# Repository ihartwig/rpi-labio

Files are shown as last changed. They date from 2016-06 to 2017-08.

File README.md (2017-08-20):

# rpi-labio

Together with the JTAG debugger and cover with motor mounts, this Raspberry Pi breakout board forms a complete kit for embedded systems labs in ARM baremetal and linux. This kit has been used for several semesters at [CMU ECE](https://www.ece.cmu.edu/~ece349/).

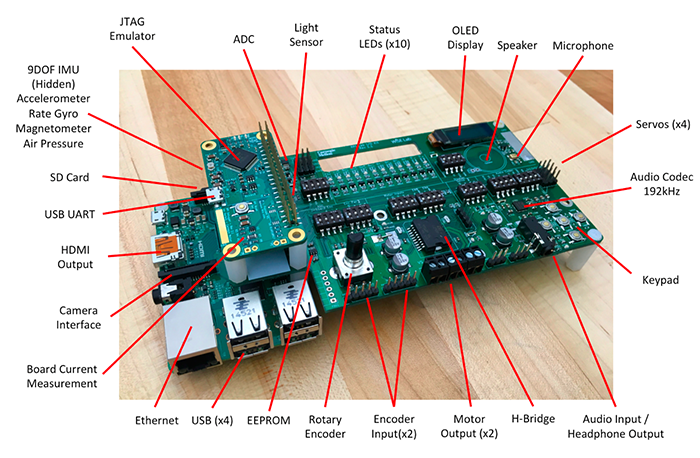
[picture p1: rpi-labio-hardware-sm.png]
labio hardware list


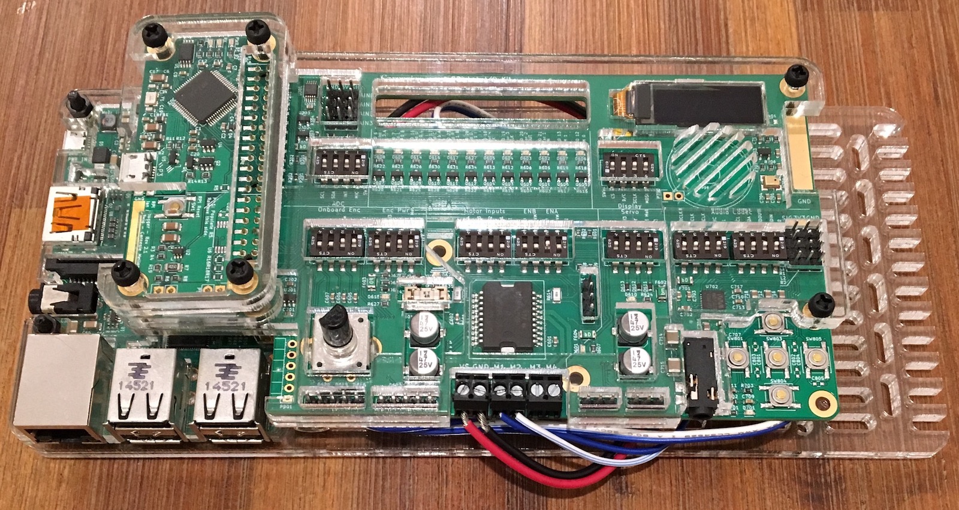
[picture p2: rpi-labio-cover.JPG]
labio with protective cover


This single, compact board extends a Raspberry Pi 0 or 2 for a full range of labs combining embedded processing with real-world sensors and transducers. All parts are optional and can be disconnected in favor of other plugged in hardware. Together, the sensor kit exercises almost all serial and digital I/O available on the Raspberry Pi. For more details check out the [schematic](https://github.com/ihartwig/rpi-labio/blob/master/pcb/labio.pdf) and [board](https://github.com/ihartwig/rpi-labio/blob/master/pcb/svg/labio-brd.svg).

## I/O

* OLED Display
* 10-DOF IMU (Accelerometer + Compass + Gyroscope + Pressure)
* Audio Codec with speaker, microphone, and headset port
* D-Pad Buttons
* Servo Headers with configurable voltage
* Full-Bridge for 2 DC motors or 1 stepper motor
* Encoder Headers with configurable voltage
* Rotary Encoder
* ADC with optional differential amplifier
* LED indicators on most digital outputs

## Example Labs

* Arcade style games with screen, d-pad, and rotary encoder
* Guitar tuner with microphone, speaker, codec, and screen
* MP3 player with codec and headphone port
* The useless machine with servo and buttons
* Self-balancing robot with IMU, motor controller, and encoders
* Energy-aware computing with ADC and power shunt (on board for motors, off board for RPi)
* And more!

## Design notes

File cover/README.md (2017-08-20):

# rpi-labio Protective Cover

The rpi-labio, debugger, and pi kit can come with a laser cut acrylic and standoff kit for increased robustness. The cover consists of 2 layers of 3mm (1/8") acrylic on the top and bottom of the boards. The layers can be configured for Pi 0/2/3 and several Pololu motor mounts including a dual-motor self-balancing kit.

The mounting holes on Raspberry Pi boards are 2.75mm (for M2.5 screws), but the labio and debugger have 3mm holes (for M3 or 4-40 screws). Nylon M3 or 4-40 screws are a tight fit but easier to find. Nylon screws are also recommended to keep the outside of the cover plastic.

Cover variants B, C, D require 1 sq. ft. of acrylic sheet. Variant A requires 1.33 sq. ft. of acrylic sheet (4 sq. ft. for 3).

## Top Layers

The layers on top of the debugger and labio boards are common to all configurations.

With 8.5mm tall stacking headers (11mm board to board) use 2x layer 9 per cover. If you have taller headers (14mm board to board), use 3x layer 9 per cover.

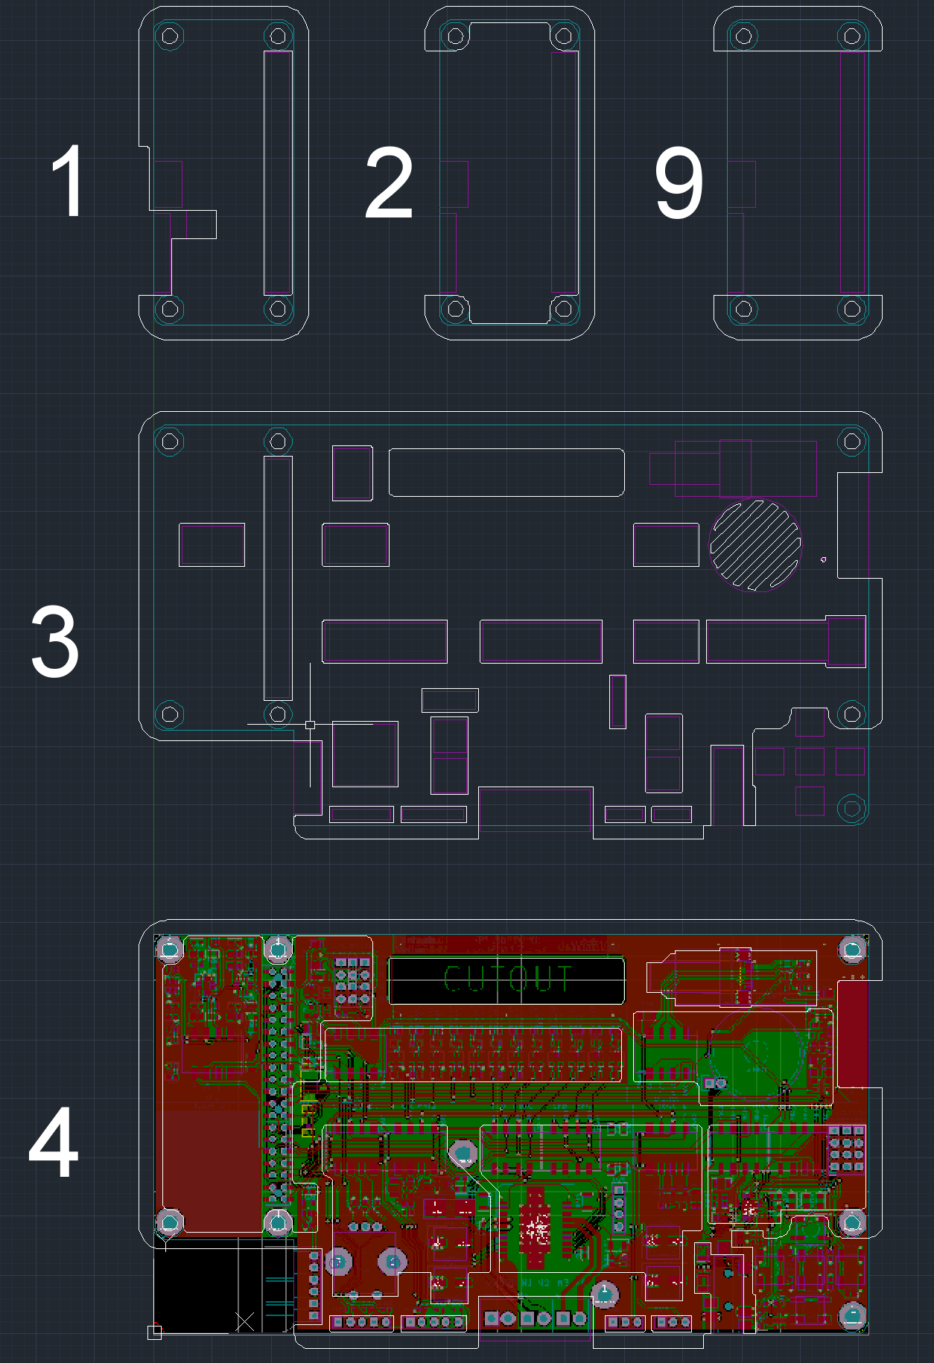
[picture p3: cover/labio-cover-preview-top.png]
labio cover preview top


## Base Layers for Pi 2/3

The base layer for Pi 2 extends beyond the labio board on both sides and includes extra protectors for the top of the Pi 2. The extra space can be used to mount a Pololu encoder gear motor or other electromechanical accessories. The smaller base is sized for 1x 20D, 2x 20D, or 1x 25D motor, and the larger base fits 1x 37D motor.

Variant A: Pi 2/3 with 37D motor
Variant B: Pi 2/3 with 1x 20D, 2x 20D, or 1x 25D motor

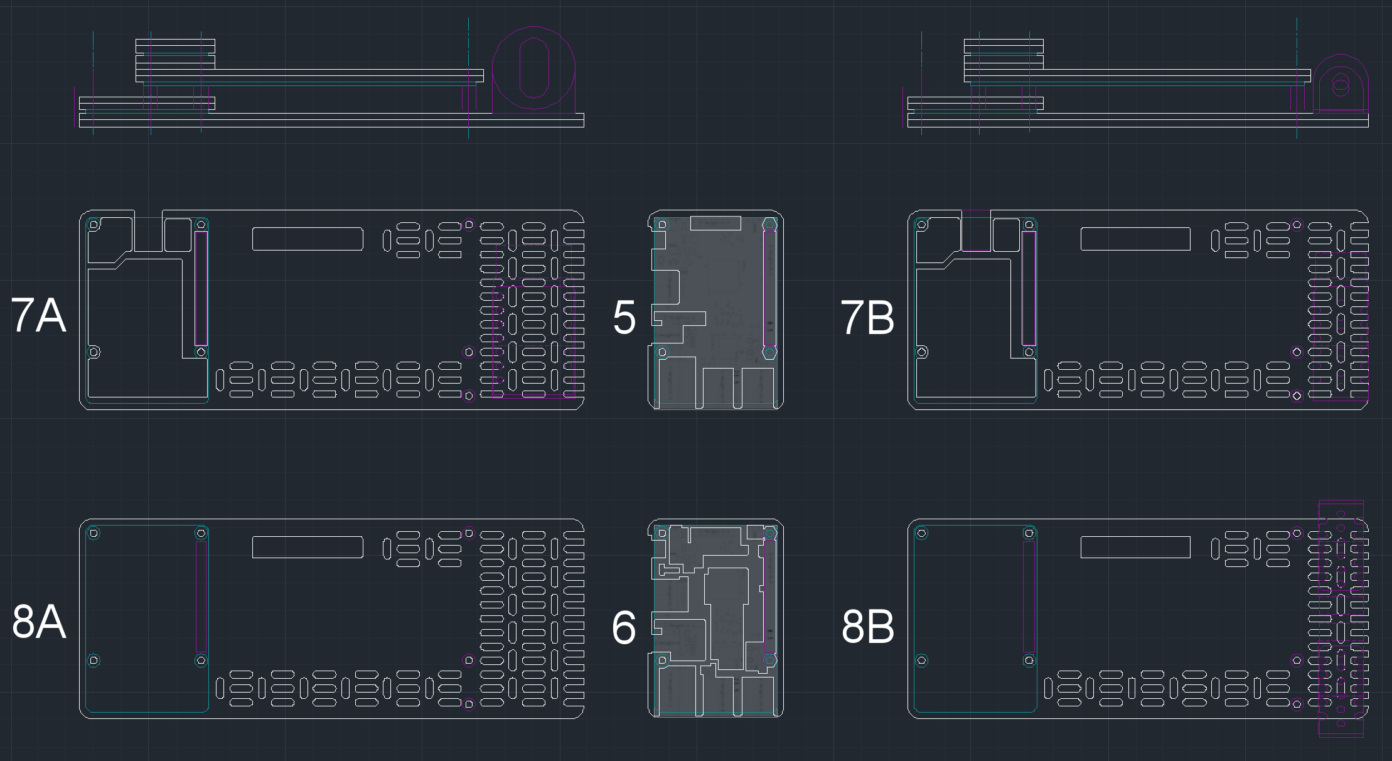
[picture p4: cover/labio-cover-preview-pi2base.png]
labio cover preview pi2 base


Orderable Parts

Description | Qty | Vendor | Vendor PN
------------|-----|--------|----------
debugger, labio 2x20 stacking header | 2 | Pololu or Toby (Samtec) | [2748](https://www.pololu.com/product/2748) or [REF-182684-02](https://www.toby.co.uk/content/catalogue/products.aspx?series=REF-18xxxx-0x)
M3 11mm or 4-40 7/16" female-female standoffs | 4 | Amico | [a12092200ux0064](http://a.co/bL8HFg3)
M3 12mm or 4-40 1/2" nylon screws | 6 | Electronics-Salon | [SCW-NLB/M3x12-100](http://a.co/i08gfTl)
M3 25mm or 4-40 1" nylon screws | 6 | uxcell | [a15062200ux0426](a15062200ux0426)
M3 or 4-40 hex nuts | 4 | uxcell | [a16033100ux0563](http://a.co/68ee8uG)
M3 or 4-40 flat washers | 6 | uxcell | [a15090700ux0161](http://a.co/8erwuEw)

We have some kits built with taller headers resulting in 14mm board to board (rather than 11mm). Adjust the orderable parts as below. Not recommended for new builds.

Description | Qty | Vendor | Vendor PN
------------|-----|--------|----------
debugger, labio 2x20 stacking header | 2 | Adafruit | [1979](https://www.adafruit.com/product/1979)
M3 14mm female-female standoffs | 4 | uxcell | [a15081800ux0063](http://a.co/6xW5v0G)
M3 12mm or 4-40 1/2" nylon screws | 6 | Electronics-Salon | [SCW-NLB/M3x12-100](http://a.co/i08gfTl)
M3 30mm or 4-40 1 1/4" nylon screws | 6 | uxcell | [SYNCTEA049689](http://a.co/3Iv3Hqf)
M3 or 4-40 hex nuts | 4 | uxcell | [a16033100ux0563](http://a.co/68ee8uG)
M3 or 4-40 flat washers | 6 | uxcell | [a15090700ux0161](http://a.co/8erwuEw)

## Base Layers for Pi 0/0W

The base layer for Pi 0 can optionally extend to the right to support Pololu 1x 20D, 2x 20D, or 1x 25D motor.

Variant C: Pi 0/0W with 1x 20D, 2x 20D, or 1x 25D motor
Variant D: Pi 0/0W only

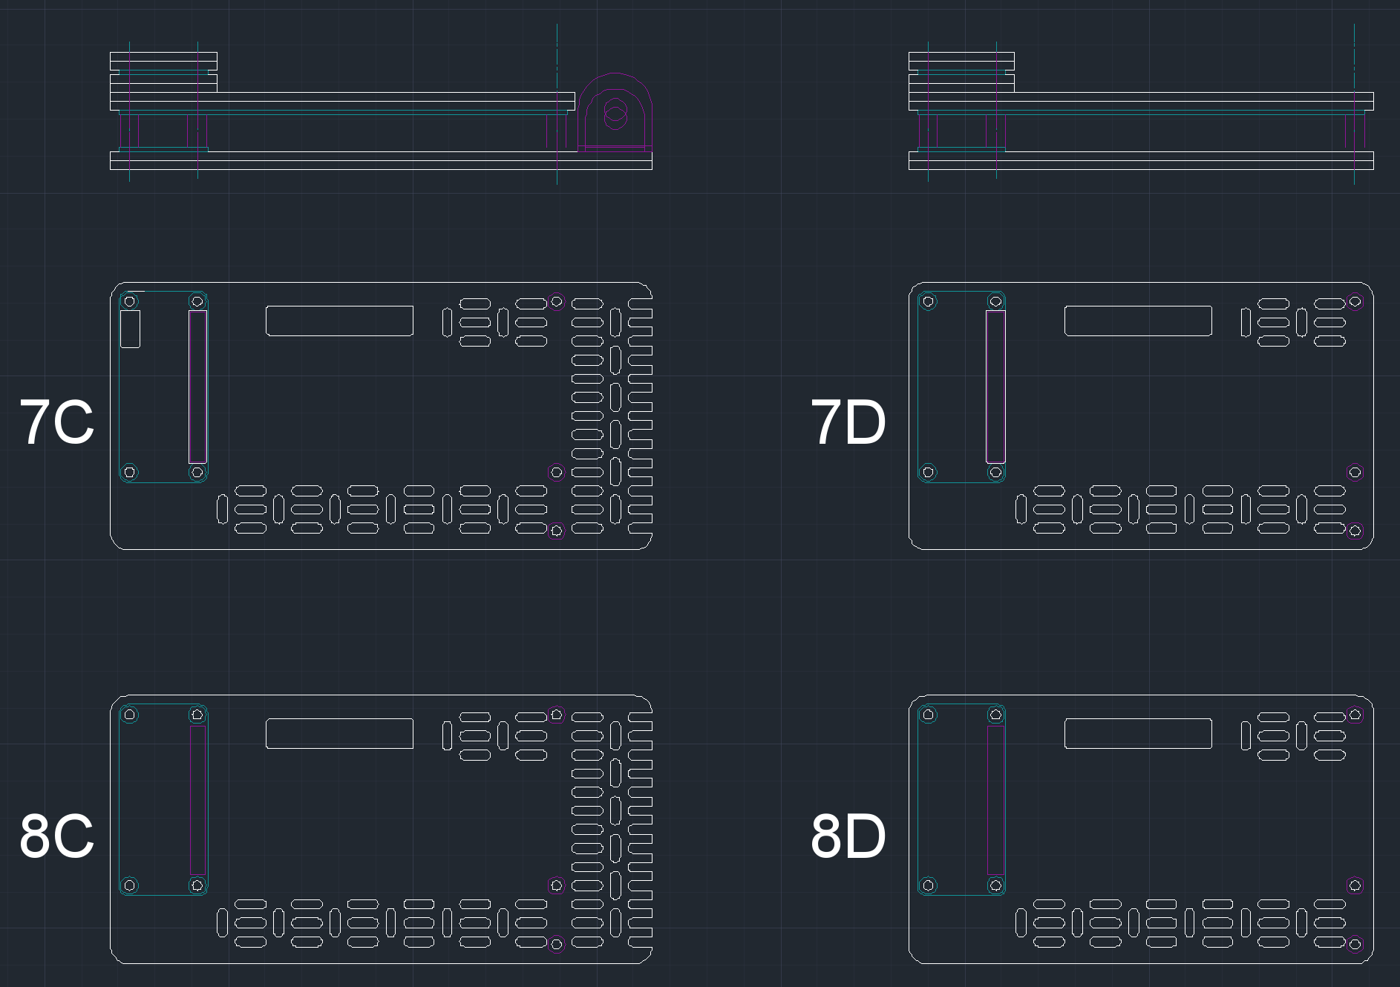
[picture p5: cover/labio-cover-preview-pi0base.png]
labio cover preview pi0 base


Orderable Parts

Description | Qty | Vendor | Vendor PN
------------|-----|--------|----------
debugger, labio 2x20 stacking header | 2 | Pololu or Toby (Samtec) | [2748](https://www.pololu.com/product/2748) or [REF-182684-02](https://www.toby.co.uk/content/catalogue/products.aspx?series=REF-18xxxx-0x)
M3 11mm or 4-40 7/16" female-female standoffs | 6 | Amico | [a12092200ux0064](http://a.co/bL8HFg3)
M3 12mm or 4-40 1/2" nylon screws | 8 | Electronics-Salon | [SCW-NLB/M3x12-100](http://a.co/i08gfTl)
M3 25mm or 4-40 1" nylon screws | 4 | uxcell | [a15062200ux0426](a15062200ux0426)
M3 or 4-40 flat washers | 6 | uxcell | [a15090700ux0161](http://a.co/8erwuEw)

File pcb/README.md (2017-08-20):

# rpi-labio/pcb

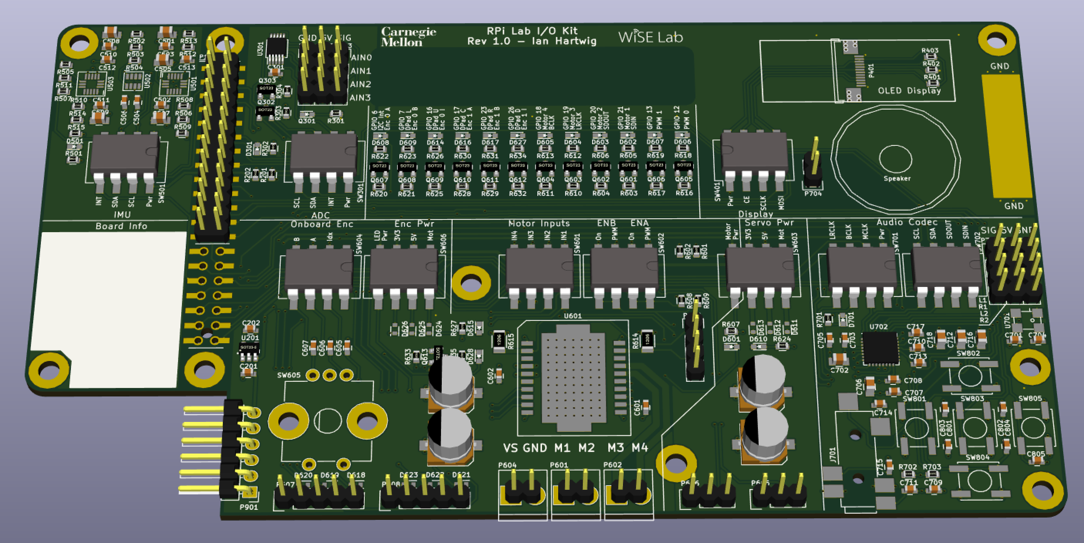
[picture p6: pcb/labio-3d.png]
labio 3d


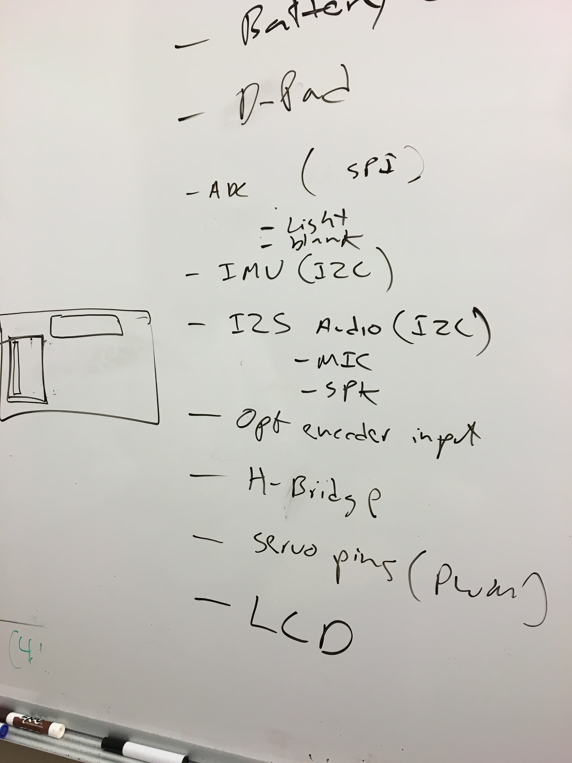
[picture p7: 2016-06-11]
docs/modules.jpg

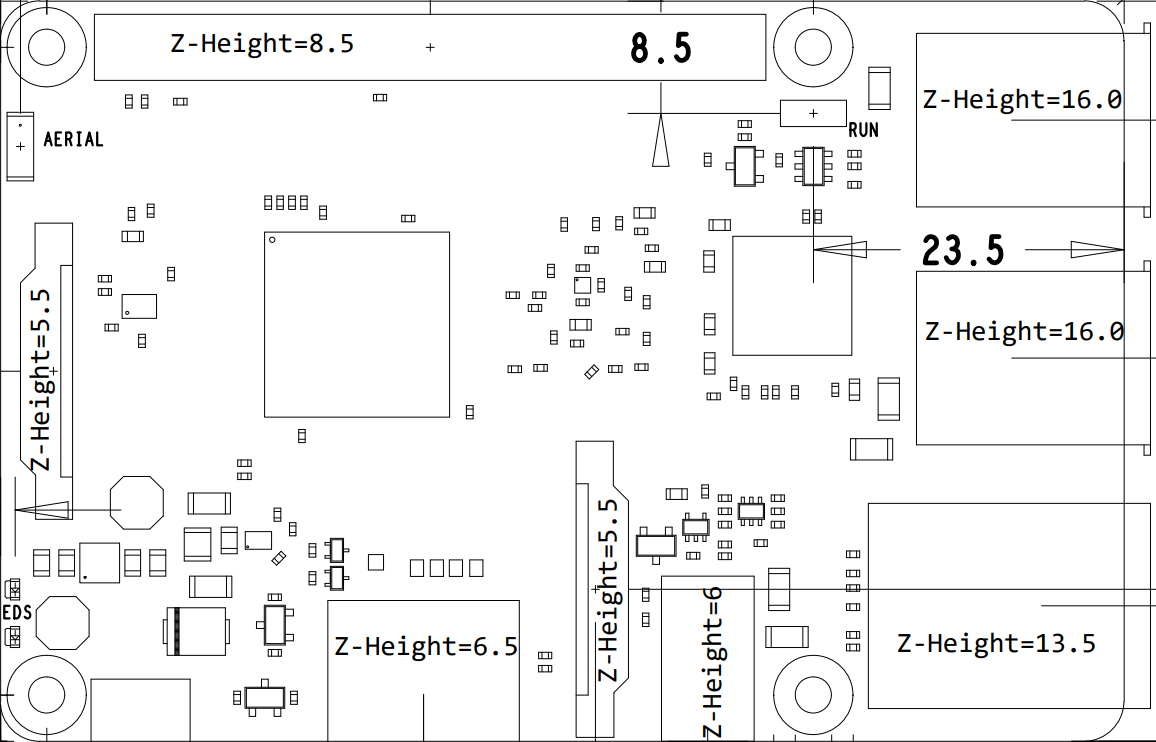
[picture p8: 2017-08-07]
cover/ref-pi3-board.png

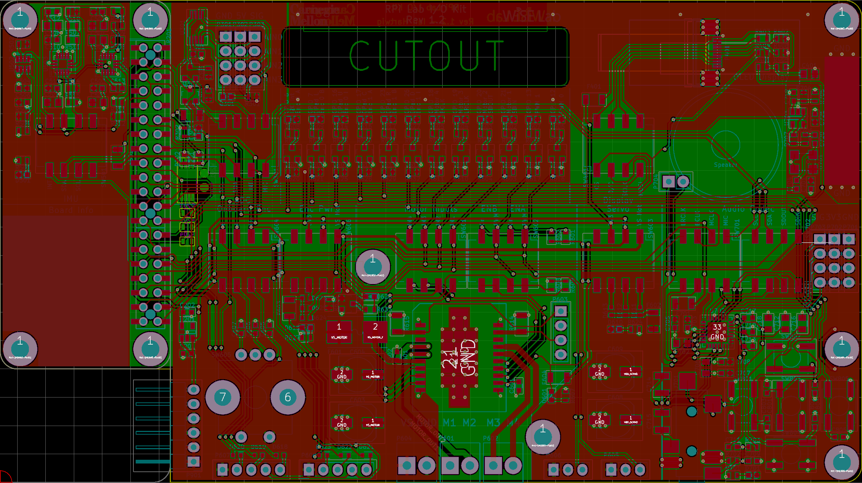
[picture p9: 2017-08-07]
cover/ref-labio-board.png

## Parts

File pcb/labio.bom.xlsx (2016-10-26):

Source | /Users/ihartwig/repos/rpi-labio/pcb/labio.sch
Kicad Rev | Eeschema 4.0.0-stable
Generated Date | Monday July 25 2016 'PMt' 11:51:32 PM
Title | Raspberry Pi Embedded Lab I/O
Company | Carnegie Mellon University
Revision | 1.2
Date Issue | 2016-08-24
Reference | Value | Footprint | Qty | Type | Mfg | Mfg Part No | Description | Digikey Part No | Comments
C201, C202, C301, C502, C503, C504, C506, C510, C511, C601, C602, C605, C606, C607, C701, C703, C705, C707, C708, C710, C713, C717, C721 | 0.1uF | Capacitors_SMD:C_0603 | 23 | SMT | Murata | GRM188R71C104KA01D | CAP CER 0.1uF ±10% 16V X7R 0603
C401 | dnp-4.7uF | Capacitors_SMD:C_0805 | 1 | DNS | Samsung | CL21A475KPFNNNG | 4.7µF 10V Ceramic Capacitor X5R 0805 | 1276-6464-1-ND | http://www.digikey.com/product-detail/en/samsung-electro-mechanics-america-inc/CL21A475KPFNNNG/1276-6464-1-ND/5958092
C501, C505, C507, C508, C509, C702, C706, C712, C716, C718 | 4.7uF | Capacitors_SMD:C_0805 | 10 | SMT | Samsung | CL21A475KPFNNNG | 4.7µF 10V Ceramic Capacitor X5R 0805 | 1276-6464-1-ND | http://www.digikey.com/product-detail/en/samsung-electro-mechanics-america-inc/CL21A475KPFNNNG/1276-6464-1-ND/5958092
C512 | 0.01uF-25V | Capacitors_SMD:C_0603 | 1 | SMT | Murata | GRM188R71H103KA01D | CAP CER 0.01uF ±10% 50V X7R 0603
C513 | 0.22uF | Capacitors_SMD:C_0603 | 1 | SMT | Murata | GRM188R71C224KA01D | CAP CER 0.22UF ±10% 16V X7R 0603
C603, C604, C608, C609 | 47uF | Capacitors_SMD:c_elec_6.3x5.8 | 4 | SMT | Nichicon | UWR1E470MCL1GB | 47µF 25V Aluminum Capacitors Radial, Can - SMD 2000 Hrs @ 85°C | 493-14562-1-ND | http://www.digikey.com/product-detail/en/nichicon/UWR1E470MCL1GB/493-14562-1-ND/5800262
C709 | 220pF | Capacitors_SMD:C_0603 | 1 | SMT | Murata | GRM188R71H221KA01D | CAP CER 220PF ±10% 50V X7R 0603
C704, C711, C719, C720 | 1uF | Capacitors_SMD:C_0603 | 4 | SMT | Samsung | CL10B105KP8NNNC | 1µF 10V Ceramic Capacitor X7R 0603 (1608 Metric) 0.063" L x 0.031" W (1.60mm x 0.80mm) | 1276-1946-1-ND | http://www.digikey.com/product-detail/en/samsung-electro-mechanics-america-inc/CL10B105KP8NNNC/1276-1946-1-ND/3890032
C714, C715 | 220uF | Capacitors_SMD:C_1210 | 2 | SMT | Samsung | CL32A227MQVNNNE | 220µF 6.3V Ceramic Capacitor X5R 1210 | 1276-3375-1-ND | http://www.digikey.com/product-detail/en/samsung-electro-mechanics-america-inc/CL32A227MQVNNNE/1276-3375-1-ND/3891461
C801, C802, C803, C804, C805 | dnp | Capacitors_SMD:C_0603 | 5 | DNS
D301, D501, D601, D602, D603, D604, D605, D606, D607, D608, D609, D610, D614, D615, D616, D617, D627, D628, D701 | Led_Small | LEDs:LED-0603 | 19 | SMT | Lite-On | LTST-C190GKT | LED GREEN CLEAR 0603 SMD | 160-1183-1-ND | http://www.digikey.com/product-detail/en/lite-on-inc/LTST-C190GKT/160-1183-1-ND/269255
D611, D612, D613, D618, D619, D620, D621, D622, D623, D624, D625, D626 | D_Small | Diodes_SMD:SOD-523 | 12 | SMT | Panasonic | DB2S20500L | DIODE SCHOTTKY 15V 200MA SSMINI2 | DB2S20500LCT-ND | http://www.digikey.com/product-detail/en/panasonic-electronic-components/DB2S20500L/DB2S20500LCT-ND/2326091
F301, F401, F501, F603, F604, F701 | F_Small | Resistors_SMD:R_1206 | 6 | SMT | Bel Fuse | 0ZCJ0010FF2E | PTC RESTTBLE 0.10A 60V CHIP 1206 | 507-1794-1-ND | http://www.digikey.com/product-detail/en/bel-fuse-inc/0ZCJ0010FF2E/507-1794-1-ND/4156222
F601 | F_Small | labio-special:OMNI-BLOCK_Fuse_10x5mm_Littelfuse | 1 | SMT | Littelfuse | 0154004.DRT | FUSE BRD MNT 4A 125VAC/VDC 2SMD | F1309CT-ND | http://www.digikey.com/product-detail/en/littelfuse-inc/0154004.DRT/F1309CT-ND/266657
F602 | F_Small | Resistors_SMD:R_1206 | 1 | SMT | Bel Fuse | 0ZCJ0050AF2E | PTC RESTTBLE 0.50A 24V CHIP 1206 | 507-1803-1-ND | http://www.digikey.com/product-detail/en/bel-fuse-inc/0ZCJ0050AF2E/507-1803-1-ND/4156312
G1 | CMU_LOGO | labio-special:cmu_logo_fsilk_3.7mm | 1 | DNS
G2 | WISE_LOGO | labio-special:wise_logo_fsilk_2.5mm | 1 | DNS
G3 | CMU_LOGO | labio-special:cmu_logo_fcu_3.7mm | 1 | DNS
G4 | WISE_LOGO | labio-special:wise_logo_fcu_2.5mm | 1 | DNS
H1001, H1002, H1003, H1004, H1005, H1006, H1007, H1008, H1009 | hole | labio-special:hole-m3 | 9 | DNS
IC201 | AT24CS32-XHM | Housings_SSOP:TSSOP-8_4.4x3mm_Pitch0.65mm | 1 | DNS
J701 | JACK_TRRS_6PINS | labio-special:3.5mm-Jack-CUI-SJ-4351X | 1 | SMT | CUI Inc | SJ-43515RS-SMT-TR | 3.50mm (0.141", 1/8", Mini Plug) - Headphone Phone Jack Multiple Connector Solder | CP-43515RSSJCT-ND | http://www.digikey.com/product-detail/en/cui-inc/SJ-43515RS-SMT-TR/CP-43515RSSJCT-ND/669732
P201 | CONN_02X20 | labio-special:Pin_Header_Straight_TH-SMT-NoPaste_2x20 | 1 | DNS
P301, P302, P303, P603, P701, P702, P703 | CONN_01X04 | Pin_Headers:Pin_Header_Straight_1x04 | 7 | TH | Harwin, Inc. | M20-9990446 | 4 Positions Header, Unshrouded, Breakaway Connector 0.100" (2.54mm) Through Hole Tin | 952-2266-ND | http://www.digikey.com/product-detail/en/harwin-inc/M20-9990446/952-2266-ND/3728230
P401 | SFV12R-1ST__HLF | labio-special:SFVxxR-xSTxxHLF | 1 | SMT | Amphenol FCI | SFV12R-3STBE1HLF | 12 Position FPC Connector Contacts, Bottom 0.020" (0.50mm) Surface Mount, Right Angle | 609-5196-1-ND | Could also use SFV12R-1STE1HLF. http://www.digikey.com/product-detail/en/amphenol-fci/SFV12R-3STBE1HLF/609-5196-1-ND/5967741
P601, P602, P604 | CONN_01X02 | labio-special:Pin_Header_Straight_1x02_Pitch3.5mm | 3 | TH | On Shore Technology, Inc. | OSTTE020104 | 2 Position Wire to Board Terminal Block Horizontal with Board 0.138" (3.50mm) Through Hole | ED2740-ND | http://www.digikey.com/product-detail/en/on-shore-technology-inc/OSTTE020104/ED2740-ND/2351816
P605, P606 | CONN_01X03 | Pin_Headers:Pin_Header_Straight_1x03 | 2 | TH | Harwin, Inc. | M20-9990346 | 3 Positions Header, Unshrouded, Breakaway Connector 0.100" (2.54mm) Through Hole Tin | 952-2264-ND | http://www.digikey.com/product-detail/en/harwin-inc/M20-9990346/952-2264-ND/3728228
P607, P608 | CONN_01X05 | Pin_Headers:Pin_Header_Straight_1x05 | 2 | TH | Harwin, Inc. | M20-9990546 | 5 Positions Header, Unshrouded, Breakaway Connector 0.100" (2.54mm) Through Hole Tin | 952-2268-ND | http://www.digikey.com/product-detail/en/harwin-inc/M20-9990546/952-2268-ND/3728232
P704 | CONN_01X02 | Pin_Headers:Pin_Header_Straight_1x02 | 1 | DNS
P901 | CONN_01X06 | Pin_Headers:Pin_Header_Angled_1x06 | 1 | DNS
Q301 | PHOTOTRANSISTOR | LEDs:LED-0603 | 1 | SMT | Everlight Electronics | PT19-21B/L41/TR8 | PHOTOTRANSISTOR FLAT BK MINI SMD | 1080-1383-1-ND | http://www.digikey.com/product-detail/en/everlight-electronics-co-ltd/PT19-21B-L41-TR8/1080-1383-1-ND/2676117
Q302, Q303, Q601, Q602, Q603, Q604, Q605, Q606, Q607, Q608, Q609, Q610, Q611, Q612, Q613 | Q_NMOS_GSD | TO_SOT_Packages_SMD:SOT-23 | 15 | SMT | ON Semiconductor | NTR5103NT1G | MOSFET N-CH 60V 0.26A SOT23 | NTR5103NT1GOSCT-ND | http://www.digikey.com/product-detail/en/on-semiconductor/NTR5103NT1G/NTR5103NT1GOSCT-ND/5801875
R201, R202, R301, R703 | 2.2k | Resistors_SMD:R_0603 | 4 | SMT | Vishay Dale | CRCW06032K20FKEA | RES SMD 2.2K OHM 1% 1/10W 0603
R203 | dnp-10k | Resistors_SMD:R_0603 | 1 | DNS
R204, R205 | dnp-3.9k | Resistors_SMD:R_0603 | 2 | DNS
R302, R501, R605, R606, R607, R612, R613, R618, R619, R622, R623, R624, R626, R627, R630, R631, R634, R635, R701 | 220 | Resistors_SMD:R_0603 | 19 | SMT | Vishay Dale | CRCW0603220RFKEA | RES SMD 220 OHM 1% 1/10W 0603
R303, R304, R601, R602, R704, R705, R706 | 10k | Resistors_SMD:R_0603 | 7 | SMT | Vishay Dale | CRCW060310K0FKEA | RES SMD 10K OHM 1% 1/10W 0603
R401, R402, R403, R502, R504, R506, R507, R508, R509, R510, R511, R513, R515 | 0 | Resistors_SMD:R_0603 | 13 | SMT | Vishay Dale | CRCW06030000Z0EA | RES SMD 0.0OHM JUMPER 1/10W 0603
R404, R406, R503, R512, R514 | dnp-0 | Resistors_SMD:R_0603 | 5 | DNS | Vishay Dale | CRCW06030000Z0EA | RES SMD 0.0OHM JUMPER 1/10W 0603
R405 | dnp-47k | Resistors_SMD:R_0603 | 1 | DNS | Vishay Dale | CRCW060347K0FKEA | RES SMD 47K OHM 1% 1/10W 0603
R603, R604, R608, R609, R610, R611, R616, R617, R620, R621, R625, R628, R629, R632, R633 | 20k | Resistors_SMD:R_0603 | 15 | SMT | Vishay Dale | CRCW060320K0FKEA | RES SMD 20K OHM 1% 1/10W 0603
R614, R615 | 0.01 | Resistors_SMD:R_1206 | 2 | SMT | Samsung | RUW3216FR100CS | RES SMD 0.1 OHM 1% 1W 1206 | 1276-6187-1-ND | http://www.digikey.com/product-detail/en/samsung-electro-mechanics-america-inc/RUW3216FR100CS/1276-6187-1-ND/3969159
R702 | 47k | Resistors_SMD:R_0603 | 1 | SMT | Vishay Dale | CRCW060347K0FKEA | RES SMD 47K OHM 1% 1/10W 0603
R707 | 820k | Resistors_SMD:R_0603 | 1 | SMT | Vishay Dale | CRCW0603820KFKEA | RES SMD 820K OHM 1% 1/10W 0603
SW301, SW401, SW501, SW601, SW602, SW603, SW604, SW606, SW701, SW702 | DIP_SWITCH_X04 | labio-special:DIP-8_W7.62mm_SMT | 10 | SMT | CTS Electrocomponents | 219-4MST | Dip Switch SPST 4 Position Surface Mount Slide (Standard) Actuator 100mA 20VDC | CT2194MST-ND | http://www.digikey.com/product-detail/en/cts-electrocomponents/219-4MST/CT2194MST-ND/223197
SW605 | ROT_ENC | labio-special:Rot-Enc-12mm-Horiz-Button | 1 | TH | Bourns | PEC12R-4220F-N0024 | 12 mm Incremental Encoder | PEC12R-4220F-N0024-ND | http://www.digikey.com/product-detail/en/bourns-inc/PEC12R-4220F-N0024/PEC12R-4220F-N0024-ND/4499652
SW801, SW802, SW803, SW804, SW805 | SW_PUSH | Buttons_Switches_SMD:SW_SPST_EVPBF | 5 | SMT | TE Connectivity | FSMCTTR | SWITCH TACTILE SPST-NO 0.02A 15V | 450-2133-1-ND | http://www.digikey.com/product-detail/en/FSMCTTR/450-2133-1-ND/5343813
U201 | AP7365_SOT-23-5 | TO_SOT_Packages_SMD:SOT-23-5 | 1 | SMT | Diodes | AP7365-33WG-7 | Linear Voltage Regulator IC Positive Fixed 1 Output 3.3V 600mA SOT-25 | AP7365-33WG-7DICT-ND | http://www.digikey.com/product-detail/en/diodes-incorporated/AP7365-33WG-7/AP7365-33WG-7DICT-ND/5267107
U301 | ADS1015 | Housings_SSOP:MSOP-10_3x3mm_Pitch0.5mm | 1 | SMT | TI | ADS1015IDGSR | IC ADC 12BIT I2C 3.3KSPS 10MSOP | 296-41185-1-ND | http://www.digikey.com/product-detail/en/texas-instruments/ADS1015IDGSR/296-41185-1-ND/5222640
U401 | CFAL12832D-B |  | 1 | DNS | Crystalfontz | CFAL12832D-B | 128x32 I2C Graphic OLED - ZIF | Not Available | https://www.crystalfontz.com/product/cfal12832db-graphic-128x32-oled
U501 | LSM303D | labio-special:LGA-16_3x3mm_Pitch0.5mm_ST | 1 | SMT | ST Microelectronics | LSM303DTR | ACCELEROMETER 3D MAGNO 16LGA | 497-13819-1-ND | http://www.digikey.com/product-detail/en/stmicroelectronics/LSM303DTR/497-13819-1-ND/4245539
U502 | BMP280 | labio-special:LGA-8_2.5x2.0mm_Pitch0.65mm_BMx280 | 1 | SMT | Bosch | BMP280 | Board Mount Pressure Sensors Digital Barometer 2.7uA, 300-1200hPa | Not Available | http://www.mouser.com/ProductDetail/Bosch-Sensortec/BMP280/
U503 | L3GD20H | labio-special:LGA-16_3x3mm_Pitch0.5mm_ST | 1 | SMT | ST Microelectronics | L3GD20HTR | IC MEMS MOTION SENSOR 16LLGA | 497-13931-1-ND | http://www.digikey.com/product-detail/en/stmicroelectronics/L3GD20HTR/497-13931-1-ND/4357644
U601 | L298P_PowerSO20 | labio-special:PowerSO20 | 1 | SMT | ST Microelectronics | L298P013TR | IC BRIDGE DRIVER PAR 20POWERSO | 497-3624-1-ND | http://www.digikey.com/product-detail/en/stmicroelectronics/L298P013TR/497-3624-1-ND/677613
U701 | SPU0410HR5H | labio-special:SPU0410HR5H | 1 | SMT | Knowles | SPU0410HR5H-PB | 100Hz ~ 10kHz Analog Microphone MEMS (Silicon) Omnidirectional (-42dB ±3dB @ 94dB SPL) Surface Mount | 423-1138-1-ND | http://www.digikey.com/product-detail/en/knowles/SPU0410HR5H-PB/423-1138-1-ND/2420982
U702 | WM8750 | Housings_DFN_QFN:QFN-32-1EP_5x5mm_Pitch0.5mm | 1 | SMT | Cirrus Logic | WM8750CJLGEFL | IC CODEC STEREO PORTABLE 32QFN | 598-2392-ND | http://www.digikey.com/product-detail/en/cirrus-logic-inc/WM8750CJLGEFL/598-2392-ND/5409917
U703 | OPA344_SOT23-5 | TO_SOT_Packages_SMD:SOT-23-5 | 1 | SMT | TI | OPA344NA/250 | IC OPAMP GP 1MHZ RRO SOT23-5 | OPA344NACT-ND | http://www.digikey.com/product-detail/en/texas-instruments/OPA344NA-250/OPA344NACT-ND/362263
W201, W202 | TEST_1P | Measurement_Points:Measurement_Point_Round-SMD-Pad_Small | 2 | DNS

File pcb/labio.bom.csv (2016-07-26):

Source | /Users/ihartwig/repos/rpi-labio/pcb/labio.sch
Kicad Rev | Eeschema 4.0.0-stable
Generated Date | Tuesday | July 26 | 2016 'AMt' 01:45:02 AM
Title | Not Set
Company | Not Set
Revision | Not Set
Date Issue | Not Set
Reference | Value | Footprint | Library | Library Ref
P1 | CONN_02X20 | labio-special:Pin_Header_Straight_TH-SMT-NoPaste_2x20 | conn | CONN_02X20
IC201 | dnp-AT24CS32-XHM | Housings_SSOP:TSSOP-8_4.4x3mm_Pitch0.65mm | memory | AT24CS32-XHM
R203 | dnp-10k | Resistors_SMD:R_0603 | device | R_Small
R204 | dnp-3.9k | Resistors_SMD:R_0603 | device | R_Small
R205 | dnp-3.9k | Resistors_SMD:R_0603 | device | R_Small
W202 | TEST_1P | Measurement_Points:Measurement_Point_Round-SMD-Pad_Small | conn | TEST_1P
W201 | TEST_1P | Measurement_Points:Measurement_Point_Round-SMD-Pad_Small | conn | TEST_1P
R202 | 4.7k | Resistors_SMD:R_0603 | device | R_Small
R201 | 4.7k | Resistors_SMD:R_0603 | device | R_Small
U201 | AP7365_SOT-23-5 | TO_SOT_Packages_SMD:SOT-23-5 | labio-special | AP7365_SOT-23-5
C201 | 0.1uF | Capacitors_SMD:C_0603 | device | C_Small
C202 | 0.1uF | Capacitors_SMD:C_0603 | device | C_Small
U301 | ADS1015 | Housings_SSOP:MSOP-10_3x3mm_Pitch0.5mm | labio-special | ADS1015
P301 | CONN_01X04 | Pin_Headers:Pin_Header_Straight_1x04 | conn | CONN_01X04
P302 | CONN_01X04 | Pin_Headers:Pin_Header_Straight_1x04 | conn | CONN_01X04
P303 | CONN_01X04 | Pin_Headers:Pin_Header_Straight_1x04 | conn | CONN_01X04
C301 | 0.1uF | Capacitors_SMD:C_0603 | device | C_Small
Q301 | PHOTOTRANSISTOR | LEDs:LED-0603 | labio-special | PHOTOTRANSISTOR
R301 | 1.5k | Resistors_SMD:R_0603 | device | R_Small
SW301 | DIP_SWITCH_X04 | labio-special:DIP-8_W7.62mm_SMT | labio-special | DIP_SWITCH_X04
D301 | Led_Small | LEDs:LED-0603 | device | Led_Small
R302 | 220 | Resistors_SMD:R_0603 | device | R_Small
Q303 | Q_NMOS_GSD | TO_SOT_Packages_SMD:SOT-23 | device | Q_NMOS_GSD
Q302 | Q_NMOS_GSD | TO_SOT_Packages_SMD:SOT-23 | device | Q_NMOS_GSD
R304 | 10k | Resistors_SMD:R_0603 | device | R_Small
R303 | 10k | Resistors_SMD:R_0603 | device | R_Small
P401 | SFV12R-1ST__HLF | labio-special:SFVxxR-xSTxxHLF | conn | CONN_01X12
R401 | 0 | Resistors_SMD:R_0603 | device | R_Small
SW401 | DIP_SWITCH_X04 | labio-special:DIP-8_W7.62mm_SMT | labio-special | DIP_SWITCH_X04
R403 | 0 | Resistors_SMD:R_0603 | device | R_Small
R402 | 0 | Resistors_SMD:R_0603 | device | R_Small
C505 | 4.7uF | Capacitors_SMD:C_0805 | device | C_Small
C503 | 0.1uF | Capacitors_SMD:C_0603 | device | C_Small
C502 | 0.1uF | Capacitors_SMD:C_0603 | device | C_Small
C506 | 0.1uF | Capacitors_SMD:C_0603 | device | C_Small
C504 | 0.1uF | Capacitors_SMD:C_0603 | device | C_Small
SW501 | DIP_SWITCH_X04 | labio-special:DIP-8_W7.62mm_SMT | labio-special | DIP_SWITCH_X04
D501 | Led_Small | LEDs:LED-0603 | device | Led_Small
R501 | 220 | Resistors_SMD:R_0603 | device | R_Small
C501 | 4.7uF | Capacitors_SMD:C_0805 | device | C_Small
U501 | LSM303D | labio-special:LGA-16_3x3mm_Pitch0.5mm_ST | labio-special | LSM303D
C513 | 0.22uF | Capacitors_SMD:C_0603 | device | C_Small
U502 | BMP280 | labio-special:LGA-8_2.5x2.0mm_Pitch0.65mm_BMx280 | labio-special | BMP280
R509 | 0 | Resistors_SMD:R_0603 | device | R_Small
R513 | 0 | Resistors_SMD:R_0603 | device | R_Small
R506 | 0 | Resistors_SMD:R_0603 | device | R_Small
R508 | 0 | Resistors_SMD:R_0603 | device | R_Small
R512 | dnp-0 | Resistors_SMD:R_0603 | device | R_Small
C512 | 0.01uF-25V | Capacitors_SMD:C_0603 | device | C_Small
C511 | 0.1uF | Capacitors_SMD:C_0603 | device | C_Small
C510 | 0.1uF | Capacitors_SMD:C_0603 | device | C_Small
C509 | 4.7uF | Capacitors_SMD:C_0805 | device | C_Small
R511 | 0 | Resistors_SMD:R_0603 | device | R_Small
R515 | 0 | Resistors_SMD:R_0603 | device | R_Small
R507 | 0 | Resistors_SMD:R_0603 | device | R_Small
R510 | 0 | Resistors_SMD:R_0603 | device | R_Small
R514 | dnp-0 | Resistors_SMD:R_0603 | device | R_Small
U503 | L3GD20H | labio-special:LGA-16_3x3mm_Pitch0.5mm_ST | labio-special | L3GD20H
R505 | 0 | Resistors_SMD:R_0603 | device | R_Small
C508 | 4.7uF | Capacitors_SMD:C_0805 | device | C_Small
C507 | 4.7uF | Capacitors_SMD:C_0805 | device | C_Small
R502 | 0 | Resistors_SMD:R_0603 | device | R_Small
R503 | dnp-0 | Resistors_SMD:R_0603 | device | R_Small
R504 | 0 | Resistors_SMD:R_0603 | device | R_Small
P605 | CONN_01X03 | Pin_Headers:Pin_Header_Straight_1x03 | conn | CONN_01X03
P606 | CONN_01X03 | Pin_Headers:Pin_Header_Straight_1x03 | conn | CONN_01X03
P607 | CONN_01X05 | Pin_Headers:Pin_Header_Straight_1x05 | conn | CONN_01X05
P608 | CONN_01X05 | Pin_Headers:Pin_Header_Straight_1x05 | conn | CONN_01X05
P601 | CONN_01X02 | labio-special:Pin_Header_Straight_1x02_Pitch3.5mm | conn | CONN_01X02
P602 | CONN_01X02 | labio-special:Pin_Header_Straight_1x02_Pitch3.5mm | conn | CONN_01X02
P604 | CONN_01X02 | labio-special:Pin_Header_Straight_1x02_Pitch3.5mm | conn | CONN_01X02
C601 | 0.1uF | Capacitors_SMD:C_0603 | device | C_Small
C602 | 0.1uF | Capacitors_SMD:C_0603 | device | C_Small
C603 | 47uF | Capacitors_SMD:c_elec_6.3x5.8 | device | CP_Small
C604 | 47uF | Capacitors_SMD:c_elec_6.3x5.8 | device | CP_Small
D620 | D_Small | Diodes_SMD:SOD-523 | device | D_Small
D619 | D_Small | Diodes_SMD:SOD-523 | device | D_Small
D618 | D_Small | Diodes_SMD:SOD-523 | device | D_Small
D621 | D_Small | Diodes_SMD:SOD-523 | device | D_Small
D622 | D_Small | Diodes_SMD:SOD-523 | device | D_Small
D623 | D_Small | Diodes_SMD:SOD-523 | device | D_Small
SW601 | DIP_SWITCH_X04 | labio-special:DIP-8_W7.62mm_SMT | labio-special | DIP_SWITCH_X04
SW602 | DIP_SWITCH_X04 | labio-special:DIP-8_W7.62mm_SMT | labio-special | DIP_SWITCH_X04
R614 | 0.01 | Resistors_SMD:R_1206 | device | R_Small
R615 | 0.01 | Resistors_SMD:R_1206 | device | R_Small
R608 | 20k | Resistors_SMD:R_0603 | device | R_Small
R609 | 20k | Resistors_SMD:R_0603 | device | R_Small
R602 | 1k | Resistors_SMD:R_0603 | device | R_Small
R601 | 1k | Resistors_SMD:R_0603 | device | R_Small
SW603 | DIP_SWITCH_X04 | labio-special:DIP-8_W7.62mm_SMT | labio-special | DIP_SWITCH_X04
D611 | D_Small | Diodes_SMD:SOD-523 | device | D_Small
D612 | D_Small | Diodes_SMD:SOD-523 | device | D_Small
D613 | D_Small | Diodes_SMD:SOD-523 | device | D_Small
SW606 | DIP_SWITCH_X04 | labio-special:DIP-8_W7.62mm_SMT | labio-special | DIP_SWITCH_X04
D624 | D_Small | Diodes_SMD:SOD-523 | device | D_Small
D625 | D_Small | Diodes_SMD:SOD-523 | device | D_Small
D626 | D_Small | Diodes_SMD:SOD-523 | device | D_Small
P603 | CONN_01X04 | Pin_Headers:Pin_Header_Straight_1x04 | conn | CONN_01X04
D602 | Led_Small | LEDs:LED-0603 | device | Led_Small
Q601 | Q_NMOS_GSD | TO_SOT_Packages_SMD:SOT-23 | device | Q_NMOS_GSD
R605 | 220 | Resistors_SMD:R_0603 | device | R_Small
R603 | 20k | Resistors_SMD:R_0603 | device | R_Small
D603 | Led_Small | LEDs:LED-0603 | device | Led_Small
Q602 | Q_NMOS_GSD | TO_SOT_Packages_SMD:SOT-23 | device | Q_NMOS_GSD
R606 | 220 | Resistors_SMD:R_0603 | device | R_Small
R604 | 20k | Resistors_SMD:R_0603 | device | R_Small
SW604 | DIP_SWITCH_X04 | labio-special:DIP-8_W7.62mm_SMT | labio-special | DIP_SWITCH_X04
D604 | Led_Small | LEDs:LED-0603 | device | Led_Small
Q603 | Q_NMOS_GSD | TO_SOT_Packages_SMD:SOT-23 | device | Q_NMOS_GSD
R612 | 220 | Resistors_SMD:R_0603 | device | R_Small
R610 | 20k | Resistors_SMD:R_0603 | device | R_Small
D605 | Led_Small | LEDs:LED-0603 | device | Led_Small
Q604 | Q_NMOS_GSD | TO_SOT_Packages_SMD:SOT-23 | device | Q_NMOS_GSD
R613 | 220 | Resistors_SMD:R_0603 | device | R_Small
R611 | 20k | Resistors_SMD:R_0603 | device | R_Small
D606 | Led_Small | LEDs:LED-0603 | device | Led_Small
Q605 | Q_NMOS_GSD | TO_SOT_Packages_SMD:SOT-23 | device | Q_NMOS_GSD
R618 | 220 | Resistors_SMD:R_0603 | device | R_Small
R616 | 20k | Resistors_SMD:R_0603 | device | R_Small
D607 | Led_Small | LEDs:LED-0603 | device | Led_Small
Q606 | Q_NMOS_GSD | TO_SOT_Packages_SMD:SOT-23 | device | Q_NMOS_GSD
R619 | 220 | Resistors_SMD:R_0603 | device | R_Small
R617 | 20k | Resistors_SMD:R_0603 | device | R_Small
D608 | Led_Small | LEDs:LED-0603 | device | Led_Small
Q607 | Q_NMOS_GSD | TO_SOT_Packages_SMD:SOT-23 | device | Q_NMOS_GSD
R622 | 220 | Resistors_SMD:R_0603 | device | R_Small
R620 | 20k | Resistors_SMD:R_0603 | device | R_Small
D609 | Led_Small | LEDs:LED-0603 | device | Led_Small
Q608 | Q_NMOS_GSD | TO_SOT_Packages_SMD:SOT-23 | device | Q_NMOS_GSD
R623 | 220 | Resistors_SMD:R_0603 | device | R_Small
R621 | 20k | Resistors_SMD:R_0603 | device | R_Small
D614 | Led_Small | LEDs:LED-0603 | device | Led_Small
Q609 | Q_NMOS_GSD | TO_SOT_Packages_SMD:SOT-23 | device | Q_NMOS_GSD
R626 | 220 | Resistors_SMD:R_0603 | device | R_Small
R625 | 20k | Resistors_SMD:R_0603 | device | R_Small
D616 | Led_Small | LEDs:LED-0603 | device | Led_Small
Q610 | Q_NMOS_GSD | TO_SOT_Packages_SMD:SOT-23 | device | Q_NMOS_GSD
R630 | 220 | Resistors_SMD:R_0603 | device | R_Small
R628 | 20k | Resistors_SMD:R_0603 | device | R_Small
D627 | Led_Small | LEDs:LED-0603 | device | Led_Small
Q612 | Q_NMOS_GSD | TO_SOT_Packages_SMD:SOT-23 | device | Q_NMOS_GSD
R634 | 220 | Resistors_SMD:R_0603 | device | R_Small
R632 | 20k | Resistors_SMD:R_0603 | device | R_Small
D617 | Led_Small | LEDs:LED-0603 | device | Led_Small
Q611 | Q_NMOS_GSD | TO_SOT_Packages_SMD:SOT-23 | device | Q_NMOS_GSD
R631 | 220 | Resistors_SMD:R_0603 | device | R_Small
R629 | 20k | Resistors_SMD:R_0603 | device | R_Small
C605 | 0.1uF | Capacitors_SMD:C_0603 | device | C_Small
C606 | 0.1uF | Capacitors_SMD:C_0603 | device | C_Small
C607 | 0.1uF | Capacitors_SMD:C_0603 | device | C_Small
SW605 | ROT_ENC | labio-special:Rot-Enc-12mm-Horiz-Button | labio-special | ROT_ENC
D628 | Led_Small | LEDs:LED-0603 | device | Led_Small
Q613 | Q_NMOS_GSD | TO_SOT_Packages_SMD:SOT-23 | device | Q_NMOS_GSD
R635 | 220 | Resistors_SMD:R_0603 | device | R_Small
R633 | 20k | Resistors_SMD:R_0603 | device | R_Small
D601 | Led_Small | LEDs:LED-0603 | device | Led_Small
R607 | 220 | Resistors_SMD:R_0603 | device | R_Small
D610 | Led_Small | LEDs:LED-0603 | device | Led_Small
R624 | 220 | Resistors_SMD:R_0603 | device | R_Small
D615 | Led_Small | LEDs:LED-0603 | device | Led_Small
R627 | 220 | Resistors_SMD:R_0603 | device | R_Small
C608 | 47uF | Capacitors_SMD:c_elec_6.3x5.8 | device | CP_Small
C609 | 47uF | Capacitors_SMD:c_elec_6.3x5.8 | device | CP_Small
U601 | L298P_PowerSO20 | labio-special:PowerSO20 | labio-special | L298P_PowerSO20
U702 | WM8731 | Housings_DFN_QFN:QFN-32-1EP_5x5mm_Pitch0.5mm | labio-special | WM8731
C708 | 0.1uF | Capacitors_SMD:C_0603 | device | C_Small
C707 | 0.1uF | Capacitors_SMD:C_0603 | device | C_Small
C703 | 0.1uF | Capacitors_SMD:C_0603 | device | C_Small
C705 | 0.1uF | Capacitors_SMD:C_0603 | device | C_Small
C702 | 4.7uF | Capacitors_SMD:C_0805 | device | C_Small
C706 | 4.7uF | Capacitors_SMD:C_0805 | device | C_Small
P704 | CONN_01X02 | Pin_Headers:Pin_Header_Straight_1x02 | conn | CONN_01X02
J701 | JACK_TRRS_6PINS | labio-special:3.5mm-Jack-CUI-SJ-4351X | labio-special | JACK_TRRS_6PINS
C715 | 220uF | Capacitors_SMD:C_0603 | device | C_Small
C714 | 220uF | Capacitors_SMD:C_0603 | device | C_Small
C710 | 0.1uF | Capacitors_SMD:C_0603 | device | C_Small
C712 | 4.7uF | Capacitors_SMD:C_0805 | device | C_Small
C713 | 0.1uF | Capacitors_SMD:C_0603 | device | C_Small
C716 | 4.7uF | Capacitors_SMD:C_0805 | device | C_Small
C717 | 0.1uF | Capacitors_SMD:C_0603 | device | C_Small
C718 | 4.7uF | Capacitors_SMD:C_0805 | device | C_Small
P703 | CONN_01X04 | Pin_Headers:Pin_Header_Straight_1x04 | conn | CONN_01X04
P702 | CONN_01X04 | Pin_Headers:Pin_Header_Straight_1x04 | conn | CONN_01X04
P701 | CONN_01X04 | Pin_Headers:Pin_Header_Straight_1x04 | conn | CONN_01X04
U701 | SPU0410HR5H | labio-special:SPU0410HR5H | labio-special | SPU0410HR5H
C704 | 2.2uF | Capacitors_SMD:C_0603 | device | C_Small
C701 | 0.1uF | Capacitors_SMD:C_0603 | device | C_Small
C709 | 220pF | Capacitors_SMD:C_0603 | device | C_Small
C711 | 1uF | Capacitors_SMD:C_0603 | device | C_Small
R702 | 47k | Resistors_SMD:R_0603 | device | R_Small
R703 | 2.2k | Resistors_SMD:R_0603 | device | R_Small
SW701 | DIP_SWITCH_X04 | labio-special:DIP-8_W7.62mm_SMT | labio-special | DIP_SWITCH_X04
SW702 | DIP_SWITCH_X04 | labio-special:DIP-8_W7.62mm_SMT | labio-special | DIP_SWITCH_X04
R701 | 220 | Resistors_SMD:R_0603 | device | R_Small
D701 | Led_Small | LEDs:LED-0603 | device | Led_Small
SW803 | SW_PUSH | Buttons_Switches_SMD:SW_SPST_EVPBF | device | SW_PUSH
SW804 | SW_PUSH | Buttons_Switches_SMD:SW_SPST_EVPBF | device | SW_PUSH
SW801 | SW_PUSH | Buttons_Switches_SMD:SW_SPST_EVPBF | device | SW_PUSH
SW802 | SW_PUSH | Buttons_Switches_SMD:SW_SPST_EVPBF | device | SW_PUSH
C801 | dnp | Capacitors_SMD:C_0603 | device | C_Small
C804 | dnp | Capacitors_SMD:C_0603 | device | C_Small
C803 | dnp | Capacitors_SMD:C_0603 | device | C_Small
C802 | dnp | Capacitors_SMD:C_0603 | device | C_Small
SW805 | SW_PUSH | Buttons_Switches_SMD:SW_SPST_EVPBF | device | SW_PUSH
C805 | dnp | Capacitors_SMD:C_0603 | device | C_Small
P901 | CONN_01X06 | Pin_Headers:Pin_Header_Angled_1x06 | conn | CONN_01X06
H1001 | hole | labio-special:hole-m3 | labio-special | hole
H1003 | hole | labio-special:hole-m3 | labio-special | hole
H1004 | hole | labio-special:hole-m3 | labio-special | hole
H1005 | hole | labio-special:hole-m3 | labio-special | hole
H1002 | hole | labio-special:hole-m3 | labio-special | hole
H1006 | hole | labio-special:hole-m3 | labio-special | hole
H1007 | hole | labio-special:hole-m3 | labio-special | hole
H1008 | hole | labio-special:hole-m3 | labio-special | hole
H1009 | hole | labio-special:hole-m3 | labio-special | hole
G2 | WISE_LOGO | labio-special:wise_logo_fsilk_2.5mm | wise_logo | WISE_LOGO
G4 | WISE_LOGO | labio-special:wise_logo_fcu_2.5mm | wise_logo | WISE_LOGO
G1 | CMU_LOGO | labio-special:cmu_logo_fsilk_3.7mm | cmu_logo | CMU_LOGO
G3 | CMU_LOGO | labio-special:cmu_logo_fcu_3.7mm | cmu_logo | CMU_LOGO

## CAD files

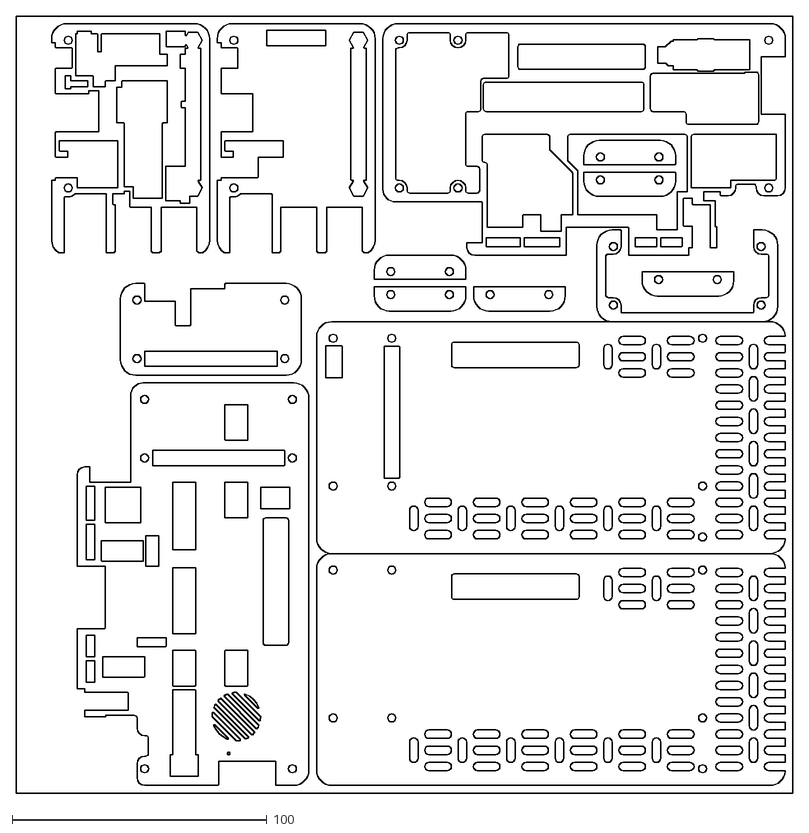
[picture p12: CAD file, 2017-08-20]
cover/labio-cover-c-set.dxf
305.0 x 305.0

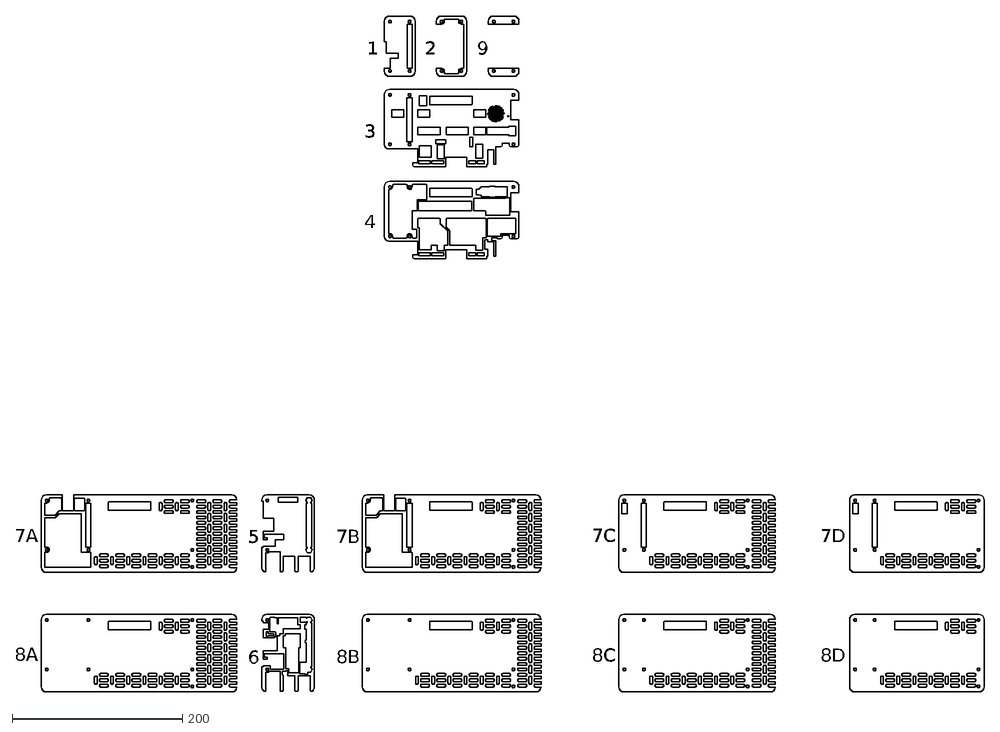
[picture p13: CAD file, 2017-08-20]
cover/labio-cover-all.dxf
1
2
3
4
7A
8A
7B
8B
7C
8C
7D
8D
5
6
9

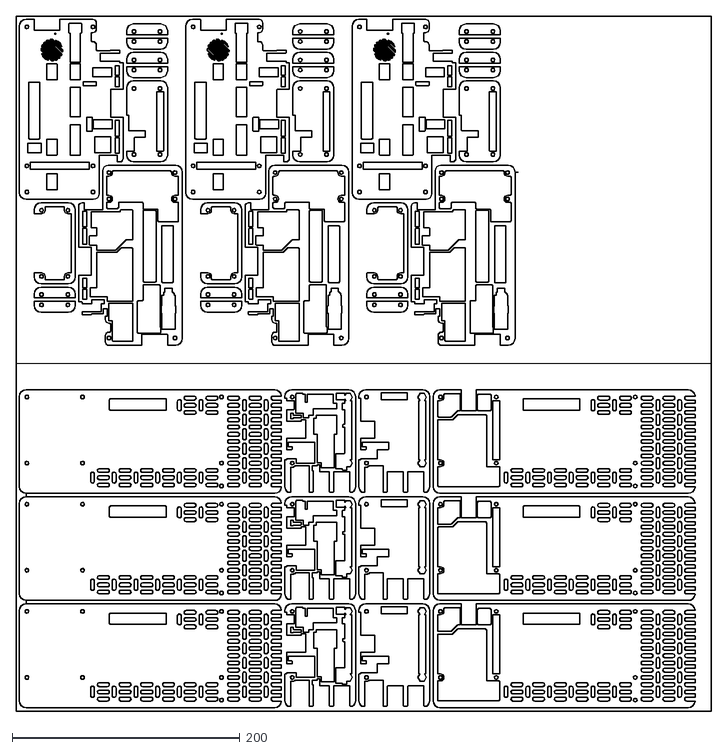
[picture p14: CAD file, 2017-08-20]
cover/labio-cover-a-set-3x.dxf
610.0 x 610.0

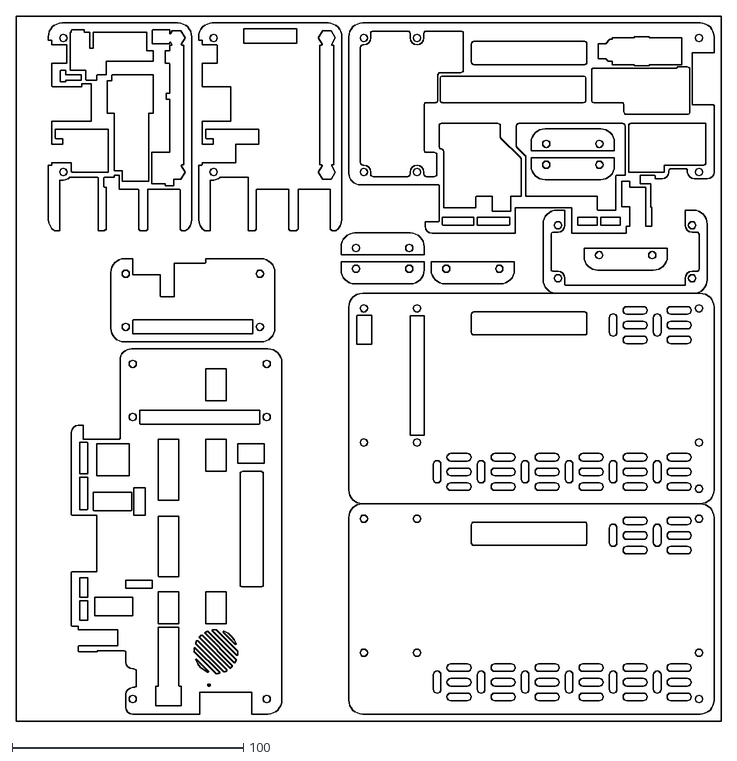
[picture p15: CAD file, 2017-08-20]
cover/labio-cover-d-set.dxf
305.0 x 305.0

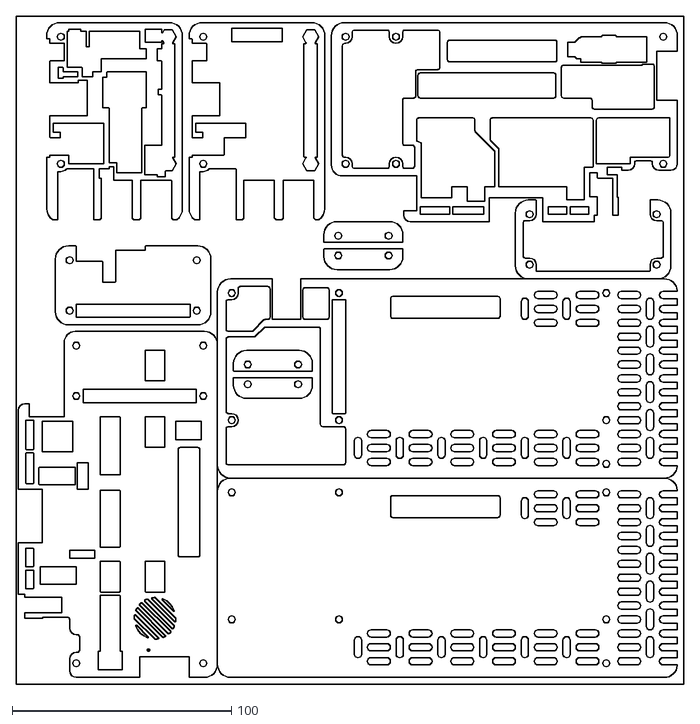
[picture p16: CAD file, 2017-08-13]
cover/labio-cover-b-set.dxf
305.0 x 305.0

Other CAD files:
pcb/footprints.dwg
cover/labio-cover.dwg

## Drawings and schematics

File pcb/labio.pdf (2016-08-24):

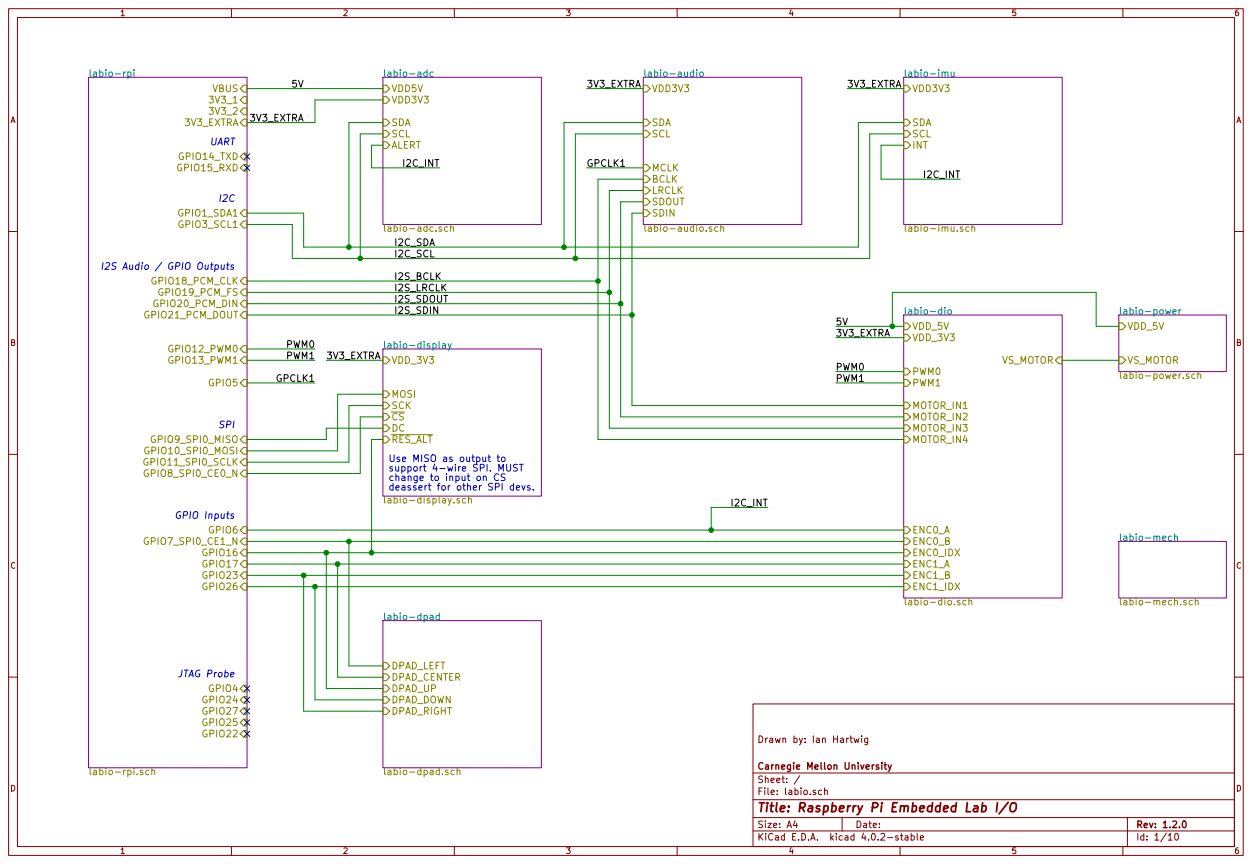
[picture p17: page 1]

labio-adc
SCL ALERT VDD5V
VDD3V3
labio-adc.sch SDA

labio-imu
labio-imu.sch VDD3V3 SCL

labio-audio.sch SDA
SCL

I2S_LRCLK
I2S_SDOUT
I2S_SDIN

MOSI
SCK
RES_ALT
labio-mech.sch Use MISO as output to
support 4-wire SPI. MUST
change to input on CS
deassert for other SPI devs.
labio-display.sch

Drawn by: Ian Hartwig

File: labio.sch Sheet: / Carnegie Mellon University

Id: 1/10 Title: Raspberry Pi Embedded Lab I/O

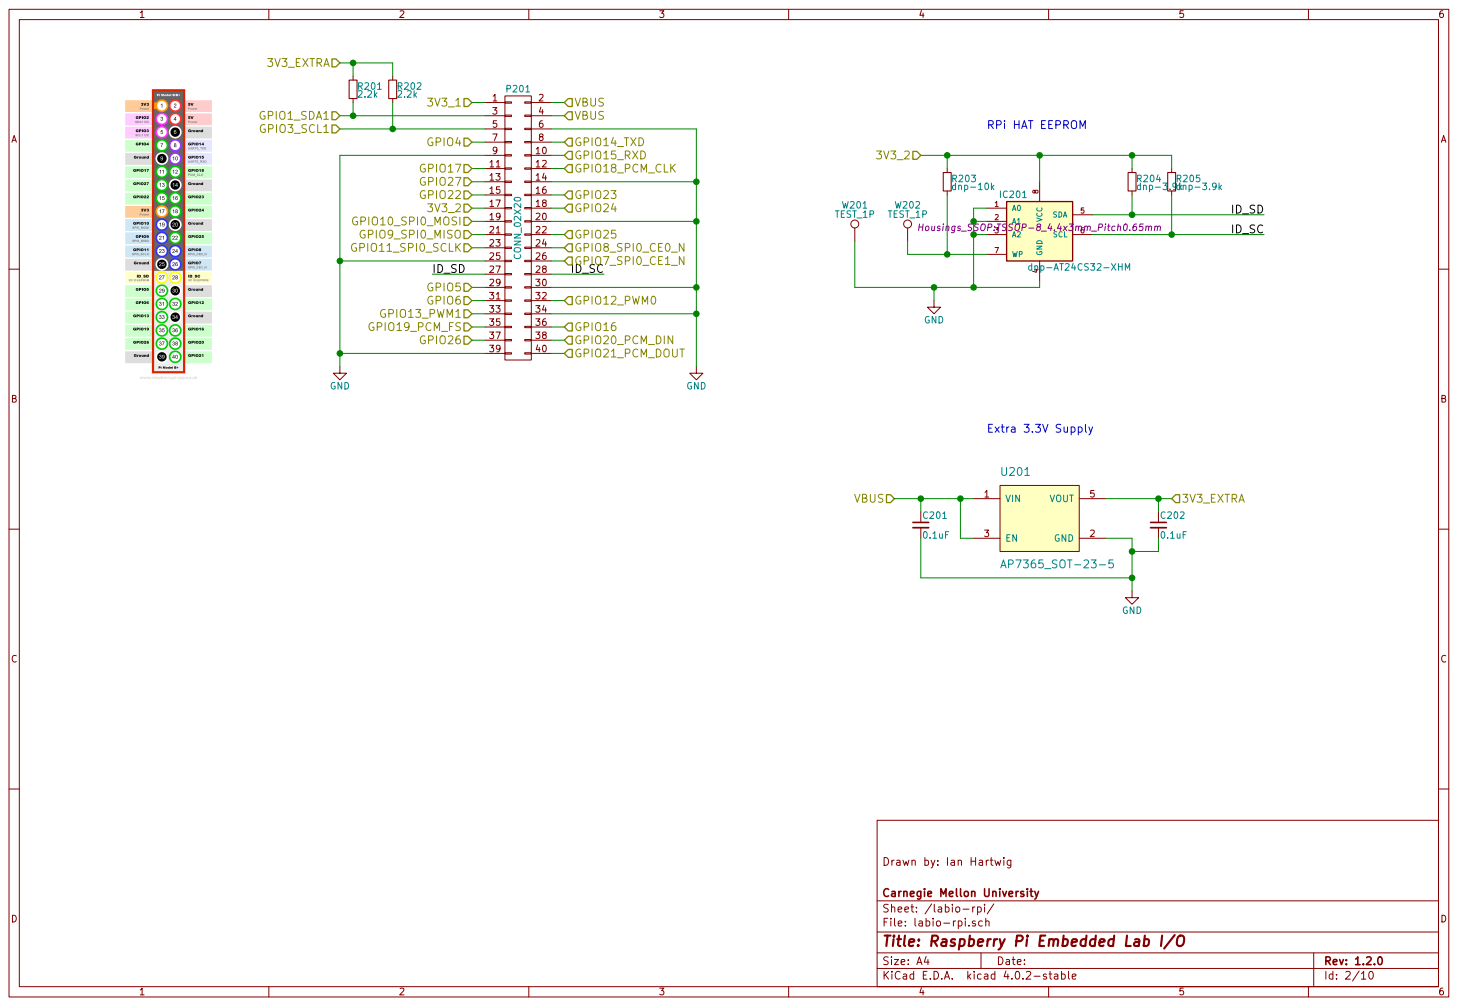
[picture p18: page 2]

4 SDA 5 SCL 6 WP 7 VCC

Drawn by: Ian Hartwig

Carnegie Mellon University
Sheet: /labio-rpi/
File: labio-rpi.sch
Id: 2/10 Title: Raspberry Pi Embedded Lab I/O

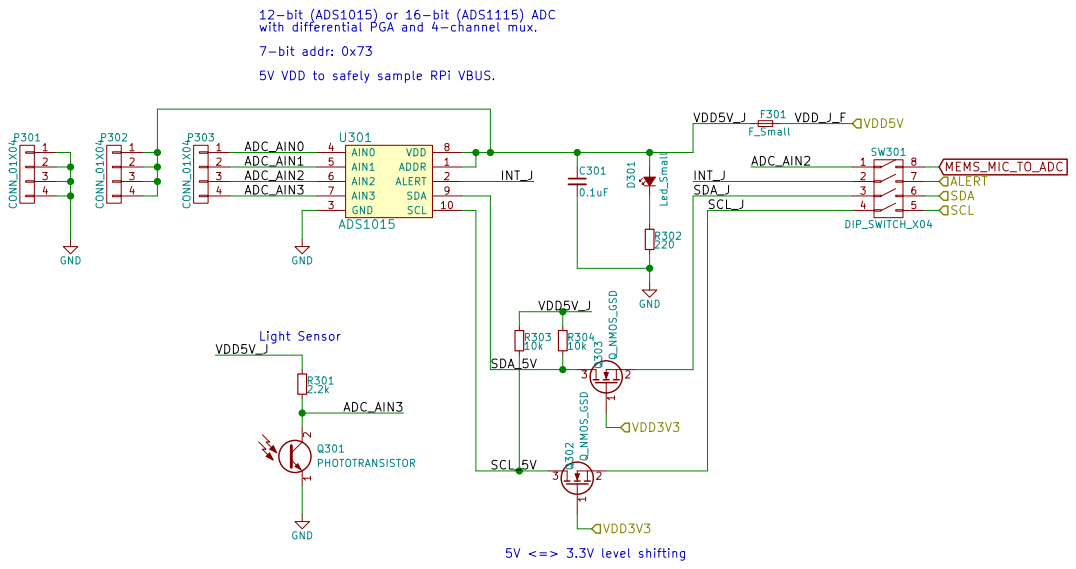
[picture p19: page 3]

12-bit (ADS1015) or 16-bit (ADS1115) ADC
with differential PGA and 4-channel mux. 7-bit addr: 0x73

5V VDD to safely sample RPi VBUS.

Drawn by: Ian Hartwig

File: labio-adc.sch Sheet: /labio-adc/ Carnegie Mellon University

Id: 3/10 Title: Raspberry Pi Embedded Lab I/O

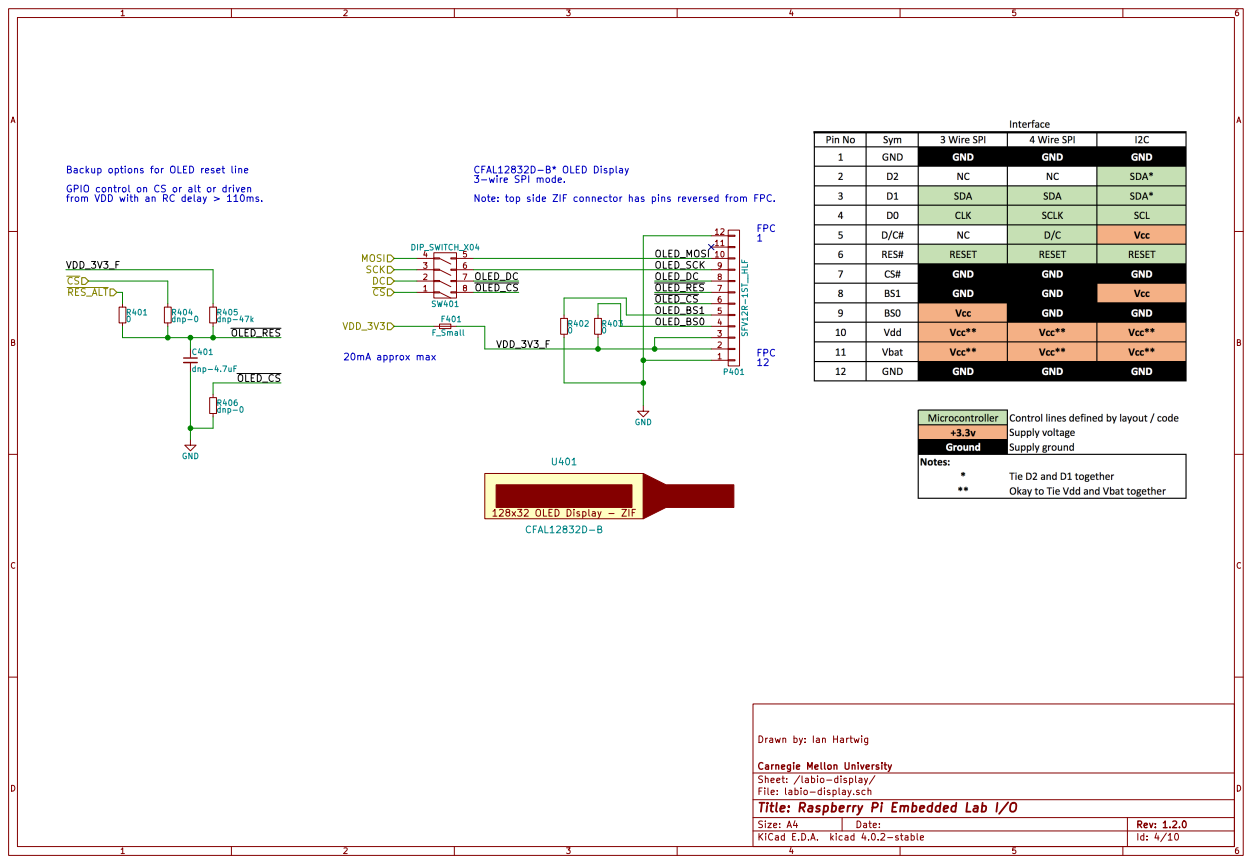
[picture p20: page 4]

Backup options for OLED reset line
GPIO control on CS or alt or driven
from VDD with an RC delay > 110ms.

Note: top side ZIF connector has pins reversed from FPC. GND VDD_3V3

11
10

6 | OLED_SCK | 9

Drawn by: Ian Hartwig

Carnegie Mellon University
Sheet: /labio-display/
File: labio-display.sch
Id: 4/10 Title: Raspberry Pi Embedded Lab I/O

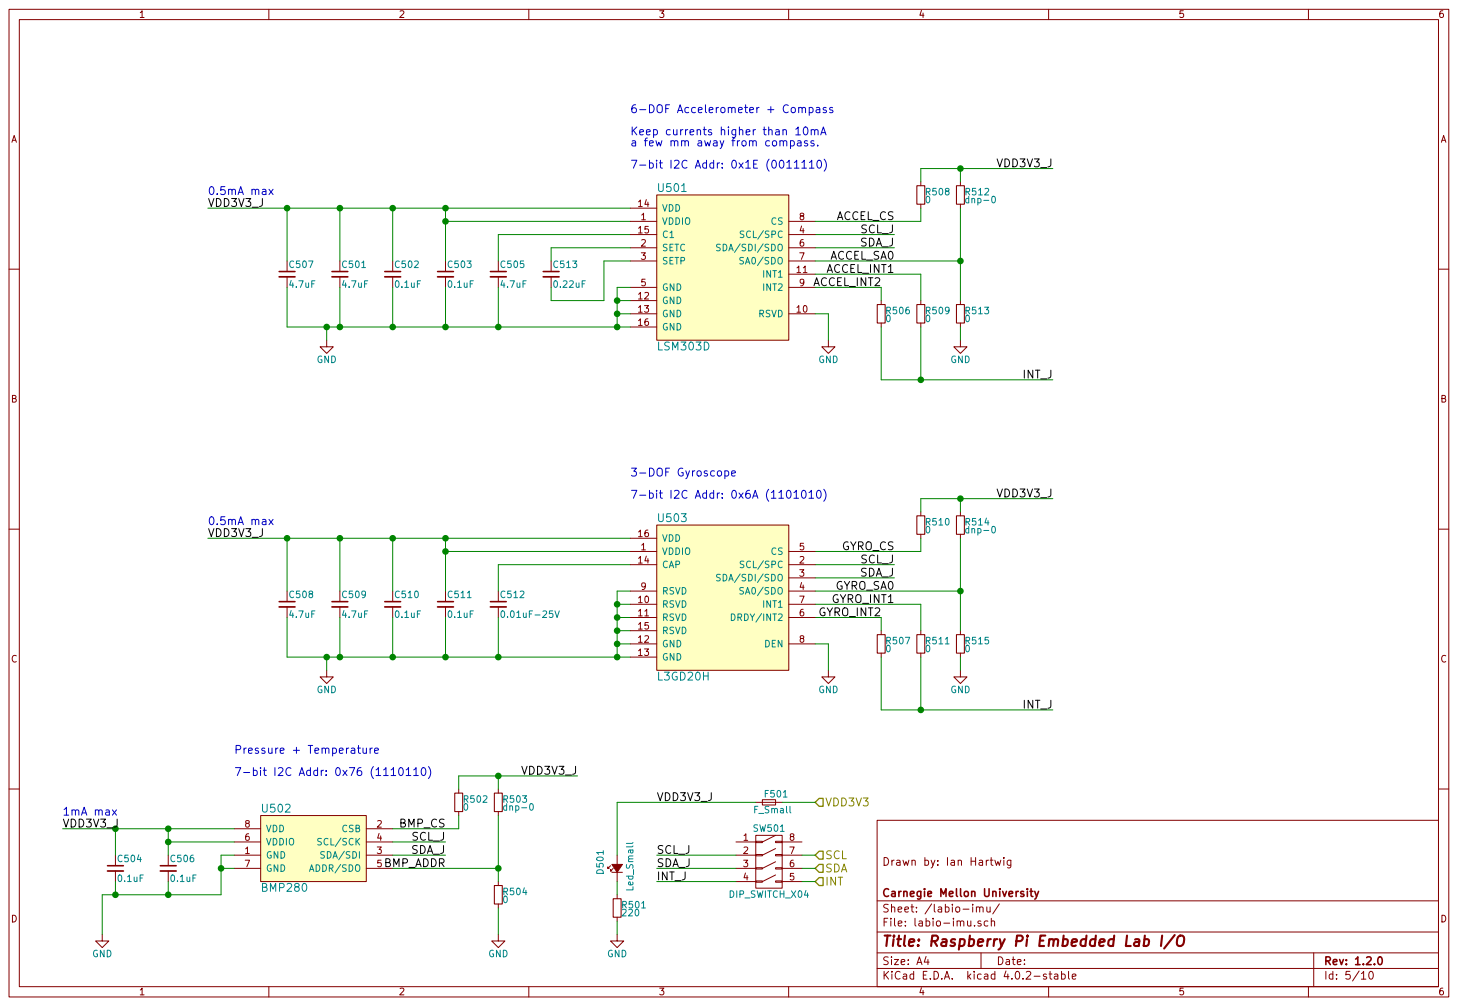
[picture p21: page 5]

6-DOF Accelerometer + Compass
Keep currents higher than 10mA
a few mm away from compass.
0.5mA max 1mA max

ACCEL_INT1
ACCEL_INT2

GYRO_INT1
GYRO_INT2

Drawn by: Ian Hartwig

File: labio-imu.sch Sheet: /labio-imu/ Carnegie Mellon University

Id: 5/10 Title: Raspberry Pi Embedded Lab I/O

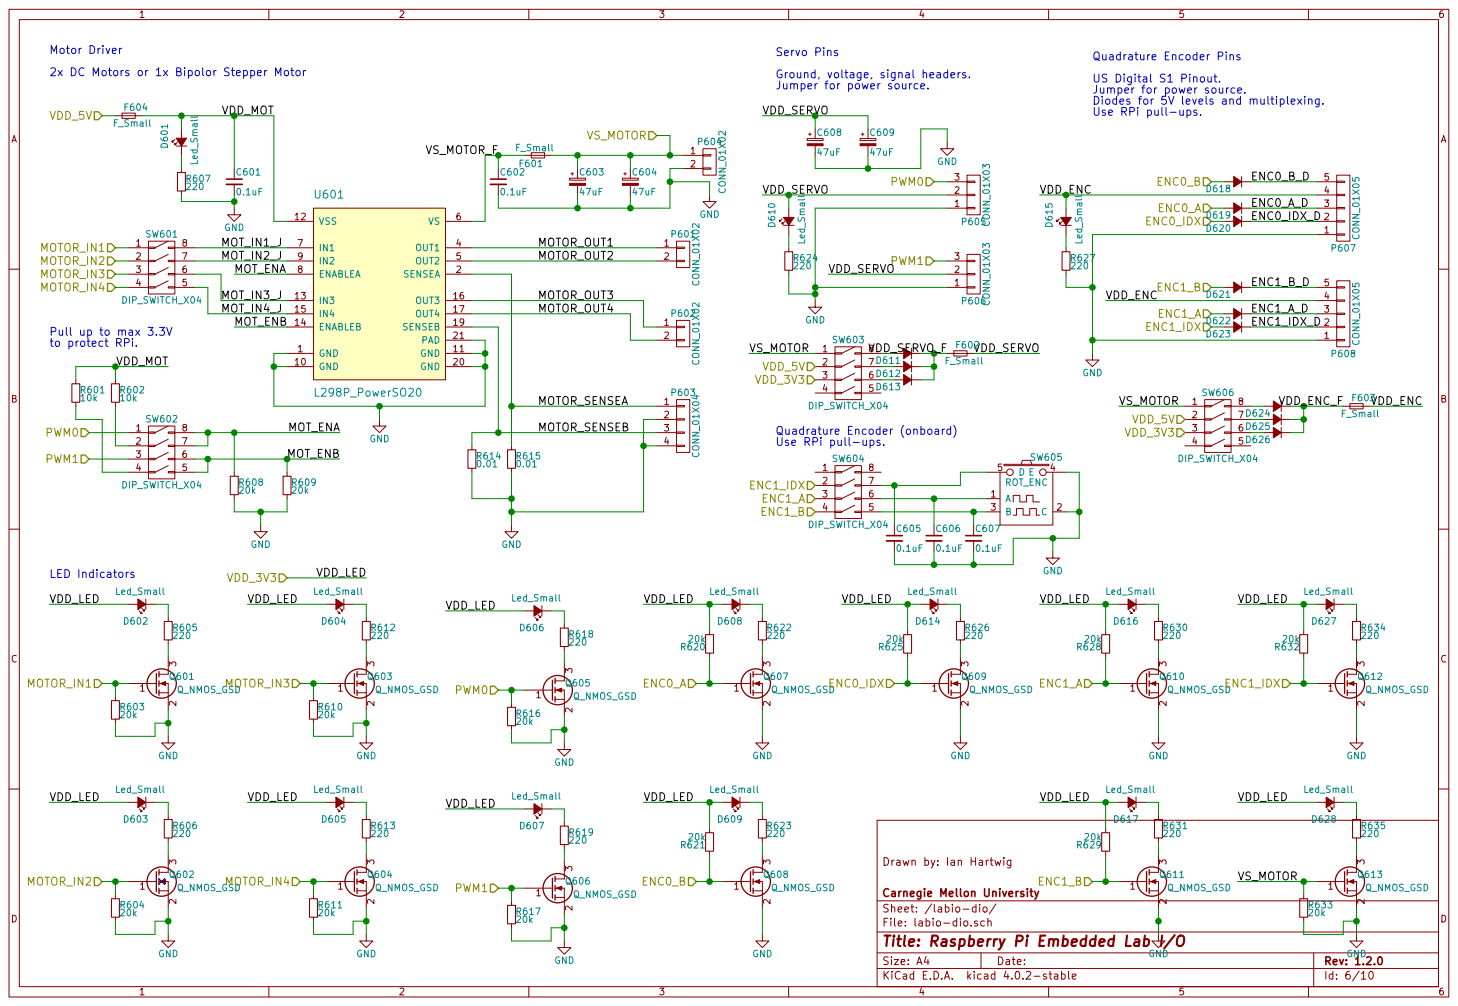
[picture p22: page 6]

Servo Pins
Ground, voltage, signal headers.

Quadrature Encoder Pins
US Digital S1 Pinout.
Jumper for power source.
Diodes for 5V levels and multiplexing.
Use RPi pull-ups.

Pull up to max 3.3V
to protect RPi.

Drawn by: Ian Hartwig

File: labio-dio.sch Sheet: /labio-dio/ Carnegie Mellon University

Id: 6/10 Title: Raspberry Pi Embedded Lab I/O

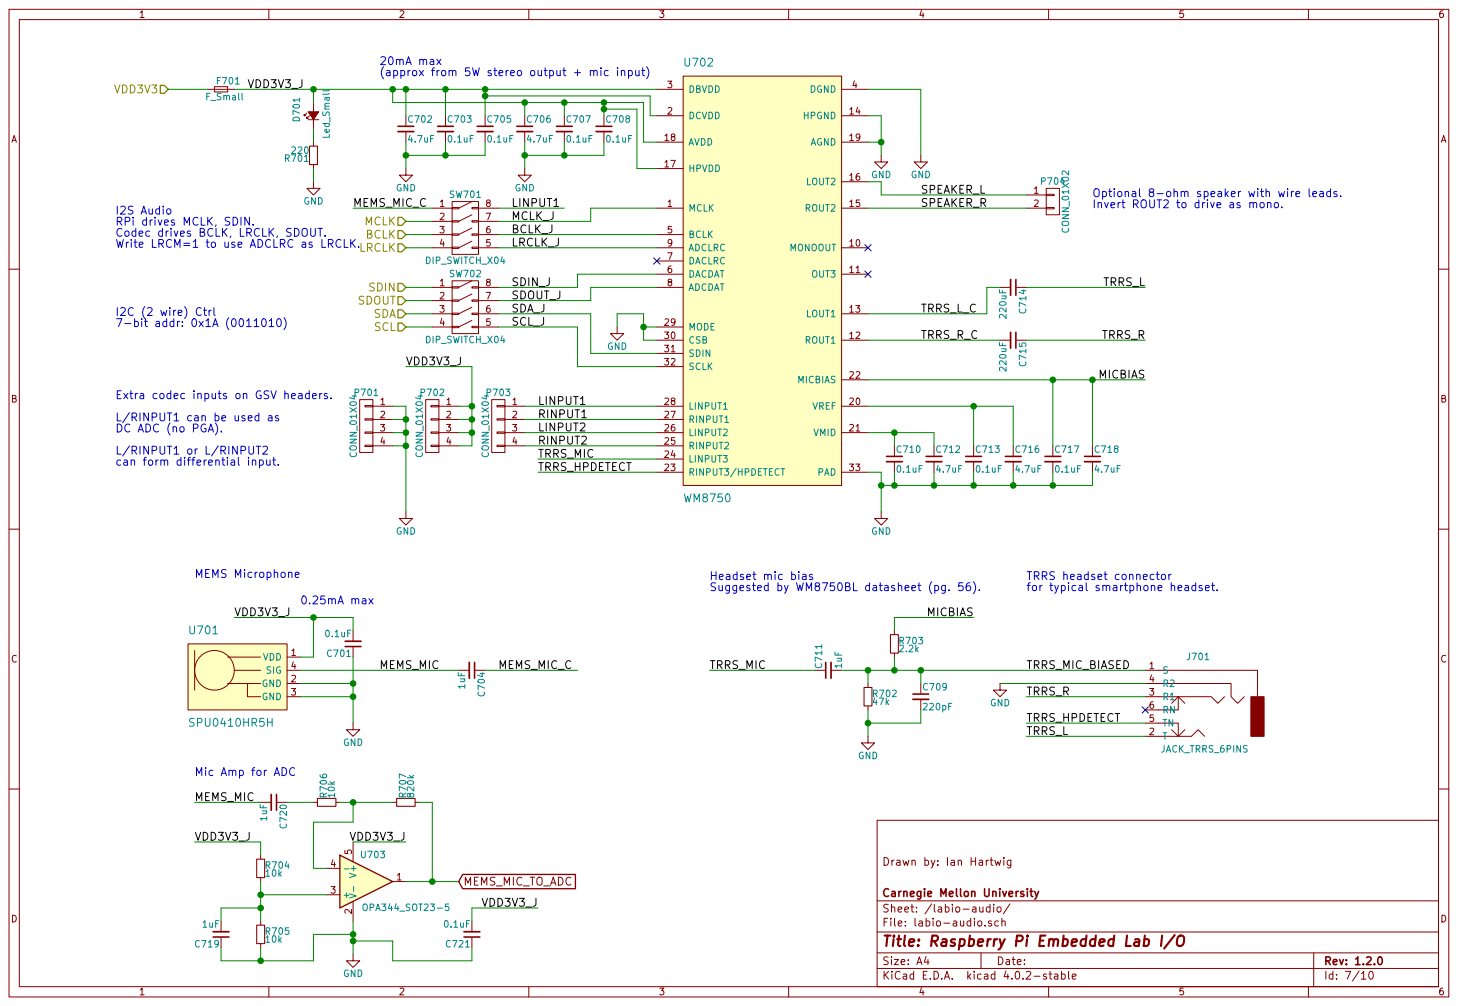
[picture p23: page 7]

20mA max
(approx from 5W stereo output + mic input)

Invert ROUT2 to drive as mono. S

I2S Audio
RPi drives MCLK, SDIN.
Codec drives BCLK, LRCLK, SDOUT.
Write LRCM=1 to use ADCLRC as LRCLK.

Extra codec inputs on GSV headers.
L/RINPUT1 can be used as
DC ADC (no PGA).
L/RINPUT1 or L/RINPUT2
can form differential input.

Headset mic bias Suggested by WM8750BL datasheet (pg. 56). 0.25mA max

TRRS headset connector
for typical smartphone headset.

Drawn by: Ian Hartwig

File: labio-audio.sch Sheet: /labio-audio/ Carnegie Mellon University

Id: 7/10 Title: Raspberry Pi Embedded Lab I/O

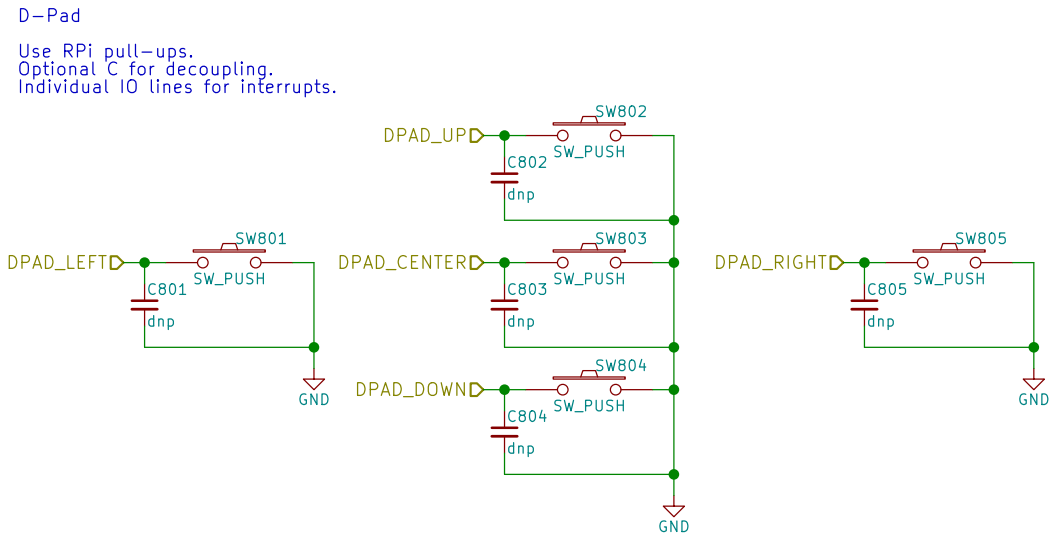
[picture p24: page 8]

SW802 SW_PUSH D-Pad Use RPi pull-ups.

Optional C for decoupling.
Individual IO lines for interrupts. C801

Drawn by: Ian Hartwig

Carnegie Mellon University
Sheet: /labio-dpad/
File: labio-dpad.sch
Id: 8/10 Title: Raspberry Pi Embedded Lab I/O

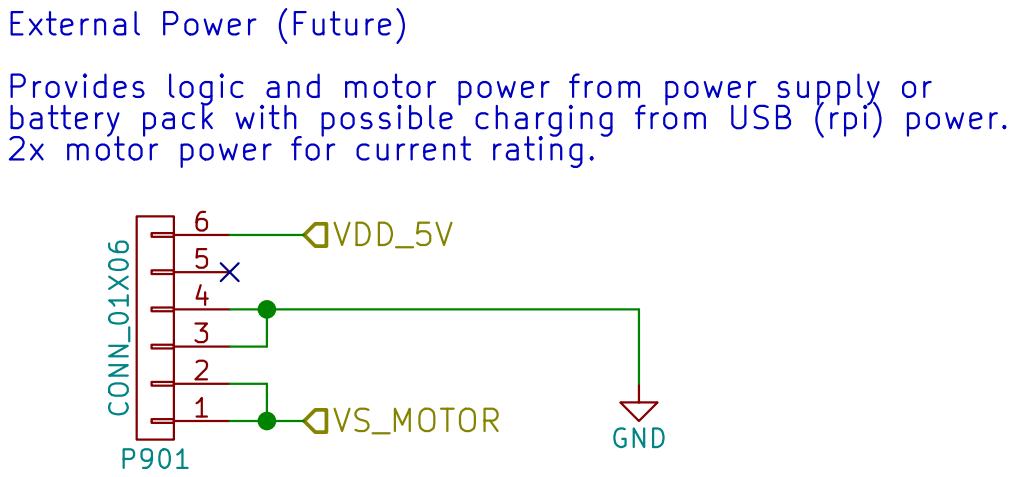
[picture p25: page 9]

External Power (Future)
Provides logic and motor power from power supply or
battery pack with possible charging from USB (rpi) power.
2x motor power for current rating.

Drawn by: Ian Hartwig

Carnegie Mellon University
Sheet: /labio-power/
File: labio-power.sch
Id: 9/10 Title: Raspberry Pi Embedded Lab I/O

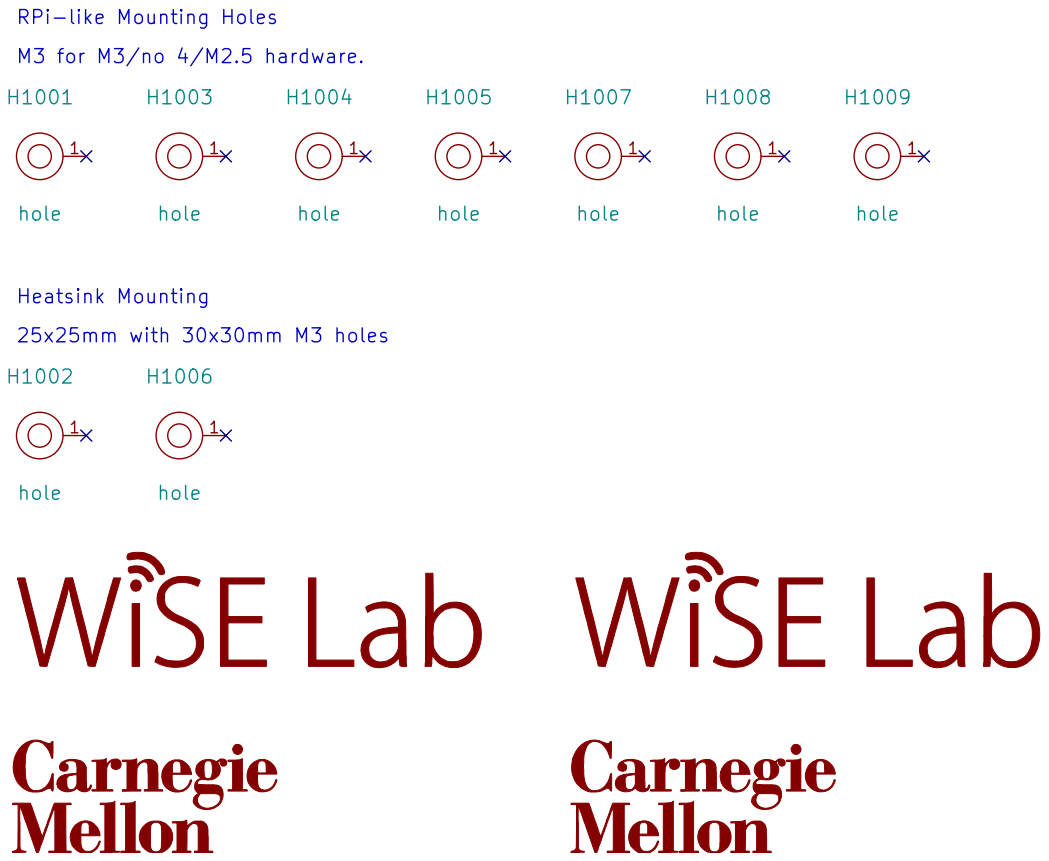
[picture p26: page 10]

hole RPi-like Mounting Holes
M3 for M3/no 4/M2.5 hardware. 1 H1002

Drawn by: Ian Hartwig

File: labio-mech.sch Sheet: /labio-mech/ Carnegie Mellon University

Id: 10/10 Title: Raspberry Pi Embedded Lab I/O

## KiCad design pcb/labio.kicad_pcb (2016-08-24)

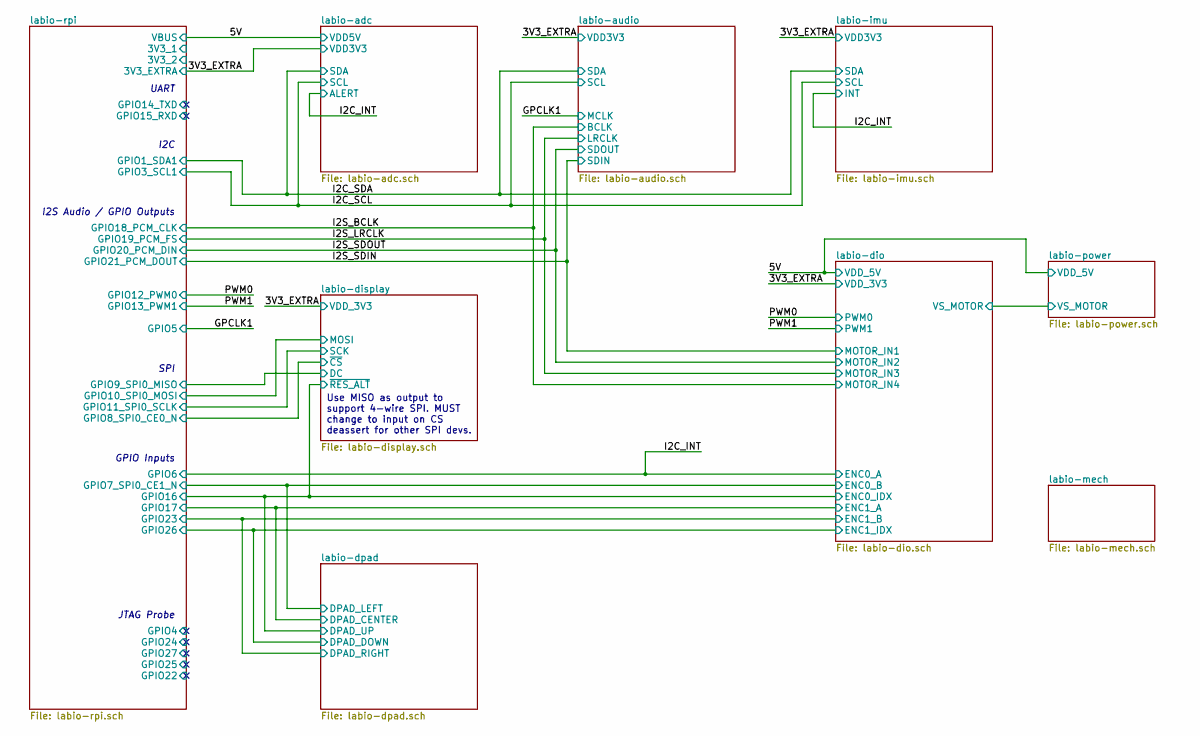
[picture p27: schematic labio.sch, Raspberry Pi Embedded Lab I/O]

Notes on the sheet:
JTAG Probe
GPIO Inputs
I2S Audio / GPIO Outputs
I2C
UART
SPI
Use MISO as output to support 4-wire SPI. MUST change to input on CS deassert for other SPI devs.

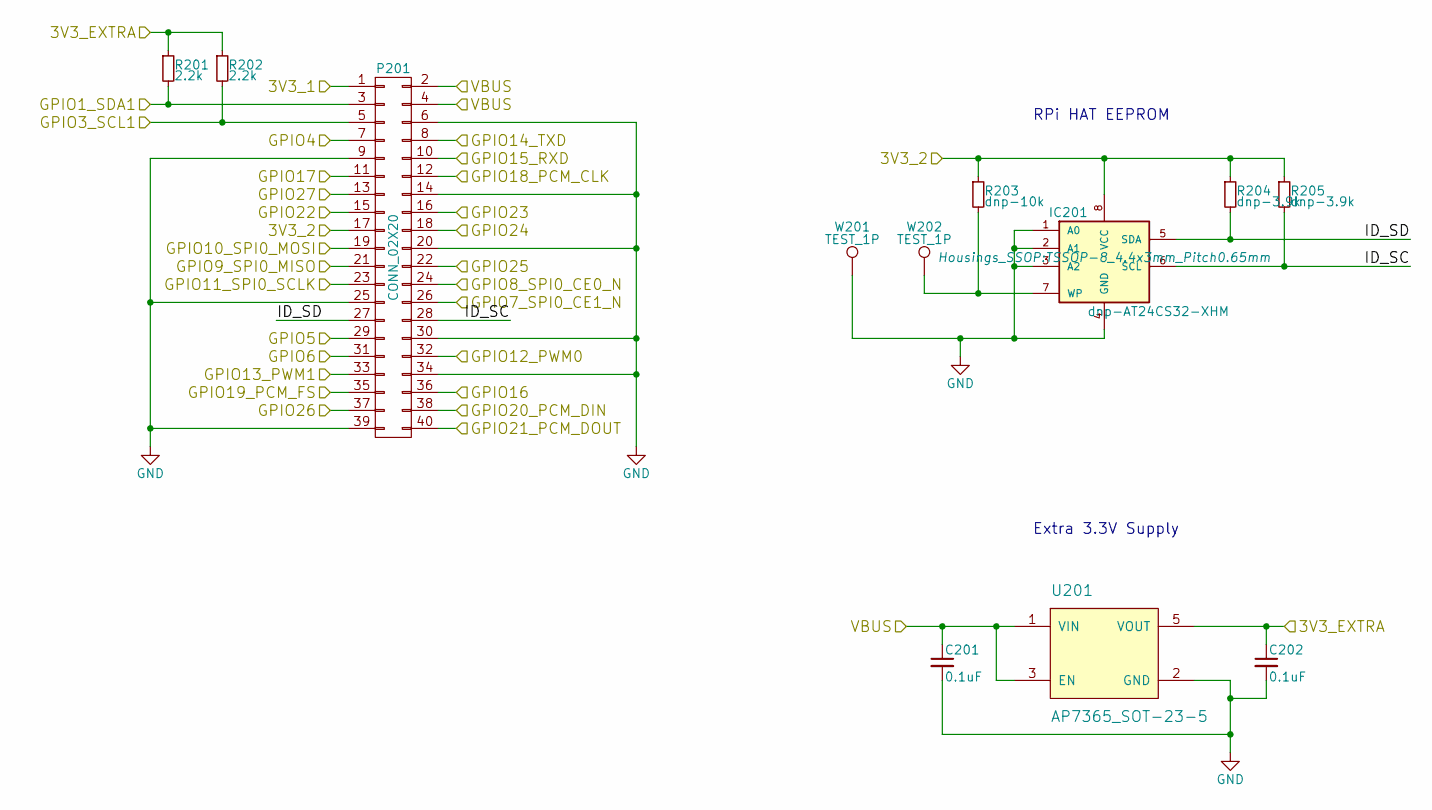
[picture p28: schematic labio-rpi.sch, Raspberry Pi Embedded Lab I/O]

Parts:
C201, C202: 0.1uF; C_0603
IC201: dnp-AT24CS32-XHM; TSSOP-8_4.4x3mm_Pitch0.65mm
P201: CONN_02X20; Pin_Header_Straight_TH-SMT-NoPaste_2x20
R201, R202: 2.2k; R_0603
R203: dnp-10k; R_0603
R204, R205: dnp-3.9k; R_0603
U201: AP7365_SOT-23-5; SOT-23-5
W201, W202: TEST_1P; Measurement_Point_Round-SMD-Pad_Small

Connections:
/3V3_EXTRA: C202.1, R201.1, R202.1, U201.5 (VOUT); also elsewhere on the board
/5V: C201.1, P201.2, P201.4, U201.1 (VIN), U201.3 (EN); also elsewhere on the board
/GPCLK1: P201.29; also elsewhere on the board
/I2C_INT: P201.31; also elsewhere on the board
/I2C_SCL: P201.5, R202.2; also elsewhere on the board
/I2C_SDA: P201.3, R201.2; also elsewhere on the board
/I2S_BCLK: P201.12; also elsewhere on the board
/I2S_LRCLK: P201.35; also elsewhere on the board
/I2S_SDIN: P201.40; also elsewhere on the board
/I2S_SDOUT: P201.38; also elsewhere on the board
/PWM0: P201.32; also elsewhere on the board
/PWM1: P201.33; also elsewhere on the board
/labio-display/DC: P201.21; also elsewhere on the board
/labio-dpad/DPAD_CENTER: P201.11; also elsewhere on the board
/labio-dpad/DPAD_DOWN: P201.37; also elsewhere on the board
/labio-dpad/DPAD_LEFT: P201.26; also elsewhere on the board
/labio-dpad/DPAD_RIGHT: P201.16; also elsewhere on the board
/labio-dpad/DPAD_UP: P201.36; also elsewhere on the board
/labio-rpi/3V3_1: P201.1
/labio-rpi/3V3_2: IC201.8 (VCC), P201.17, R203.1, R204.1, R205.1
/labio-rpi/GPIO4: P201.7
/labio-rpi/GPIO8_SPI0_CE0_N: P201.24; also elsewhere on the board
/labio-rpi/GPIO10_SPI0_MOSI: P201.19; also elsewhere on the board
/labio-rpi/GPIO11_SPI0_SCLK: P201.23; also elsewhere on the board
/labio-rpi/GPIO14_TXD: P201.8
/labio-rpi/GPIO15_RXD: P201.10
/labio-rpi/GPIO22: P201.15
/labio-rpi/GPIO24: P201.18
/labio-rpi/GPIO25: P201.22
/labio-rpi/GPIO27: P201.13
/labio-rpi/ID_SC: IC201.6 (SCL), P201.28, R205.2
/labio-rpi/ID_SD: IC201.5 (SDA), P201.27, R204.2
GND: C201.2, C202.2, IC201.1 (A0), IC201.2 (A1), IC201.3 (A2), IC201.4 (GND), P201.6, P201.9, P201.14, P201.20, P201.25, P201.30, P201.34, P201.39, U201.2 (GND), W201.1; also elsewhere on the board
unnamed: IC201.7 (WP), R203.2, W202.1

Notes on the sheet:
RPi HAT EEPROM
Extra 3.3V Supply

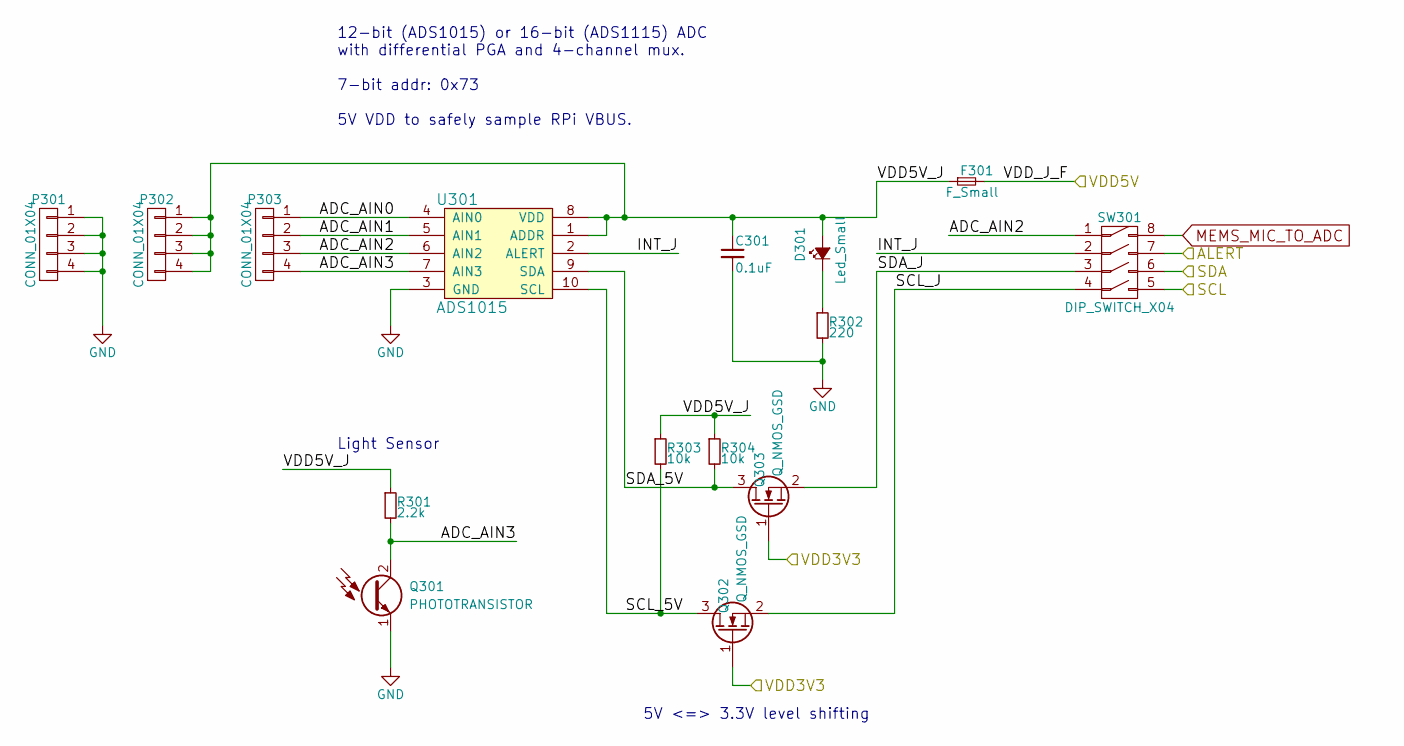
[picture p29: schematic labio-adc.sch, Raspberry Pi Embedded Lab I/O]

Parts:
C301: 0.1uF; C_0603
D301: Led_Small; LED-0603
F301: F_Small; R_1206
P301, P302, P303: CONN_01X04; Pin_Header_Straight_1x04
Q301: PHOTOTRANSISTOR; LED-0603
Q302, Q303: Q_NMOS_GSD; SOT-23
R301: 2.2k; R_0603
R302: 220; R_0603
R303, R304: 10k; R_0603
SW301: DIP_SWITCH_X04; DIP-8_W7.62mm_SMT
U301: ADS1015; MSOP-10_3x3mm_Pitch0.5mm

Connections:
/3V3_EXTRA: Q302.1 (G), Q303.1 (G); also elsewhere on the board
/5V: F301.2; also elsewhere on the board
/I2C_INT: SW301.7 (2A); also elsewhere on the board
/I2C_SCL: SW301.5 (4B); also elsewhere on the board
/I2C_SDA: SW301.6 (3B); also elsewhere on the board
/labio-adc/ADC_AIN0: P303.1, U301.4 (AIN0)
/labio-adc/ADC_AIN1: P303.2, U301.5 (AIN1)
/labio-adc/ADC_AIN2: P303.3, SW301.1 (1A), U301.6 (AIN2)
/labio-adc/ADC_AIN3: P303.4, Q301.2 (C), R301.2, U301.7 (AIN3)
/labio-adc/INT_J: SW301.2 (2A), U301.2 (ALERT)
/labio-adc/SCL_5V: Q302.3 (D), R303.2, U301.10 (SCL)
/labio-adc/SCL_J: Q302.2 (S), SW301.4 (4A)
/labio-adc/SDA_5V: Q303.3 (D), R304.2, U301.9 (SDA)
/labio-adc/SDA_J: Q303.2 (S), SW301.3 (3A)
/labio-adc/VDD5V_J: C301.1, D301.2 (A), F301.1, P302.1, P302.2, P302.3, P302.4, R301.1, R303.1, R304.1, U301.1 (ADDR), U301.8 (VDD)
GND: C301.2, P301.1, P301.2, P301.3, P301.4, Q301.1 (E), R302.2, U301.3 (GND); also elsewhere on the board
MEMS_MIC_TO_ADC: SW301.8 (1B); also elsewhere on the board
unnamed: D301.1 (K), R302.1

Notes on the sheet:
12-bit (ADS1015) or 16-bit (ADS1115) ADC with differential PGA and 4-channel mux. 7-bit addr: 0x73 5V VDD to safely sample RPi VBUS.
Light Sensor
5V <=> 3.3V level shifting

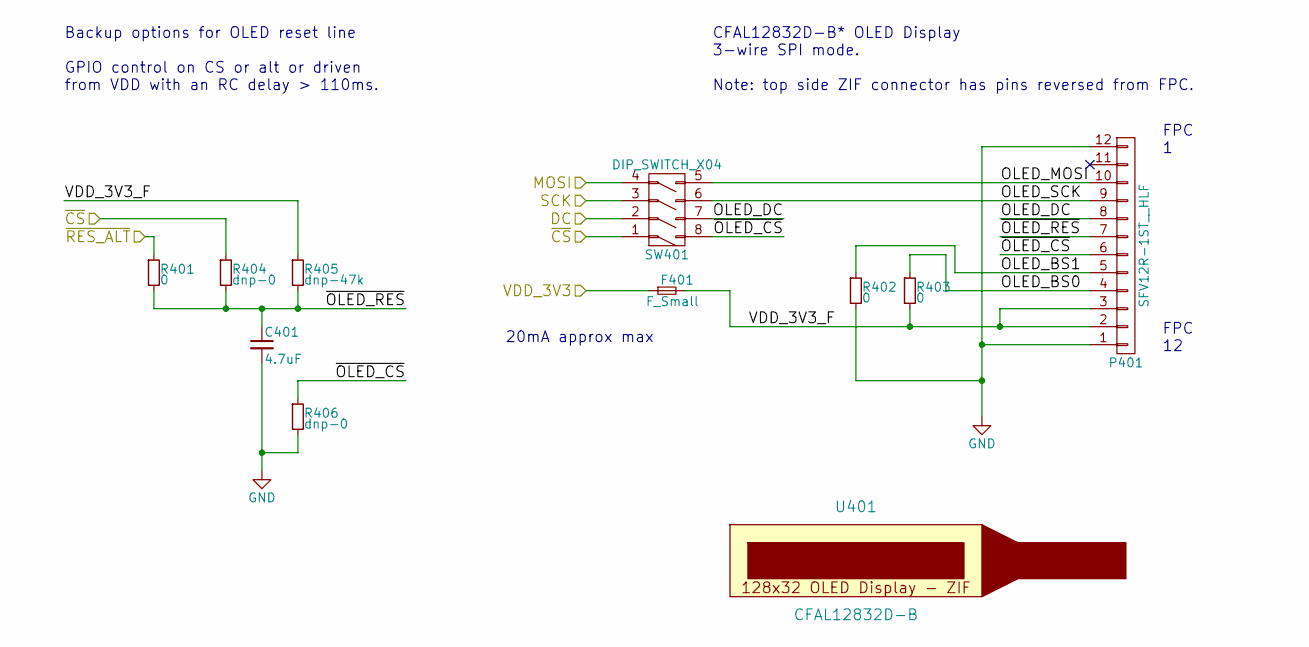
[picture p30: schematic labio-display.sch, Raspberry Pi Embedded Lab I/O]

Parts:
C401: 4.7uF; C_0805
F401: F_Small; R_1206
P401: SFV12R-1ST__HLF; SFVxxR-xSTxxHLF
R401, R402, R403: 0; R_0603
R404, R406: dnp-0; R_0603
R405: dnp-47k; R_0603
SW401: DIP_SWITCH_X04; DIP-8_W7.62mm_SMT
U401: CFAL12832D-B

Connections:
/3V3_EXTRA: F401.1; also elsewhere on the board
/labio-display/DC: SW401.2 (2A); also elsewhere on the board
/labio-display/OLED_BS0: P401.4, R403.1
/labio-display/OLED_BS1: P401.5, R402.1
/labio-display/OLED_DC: P401.8, SW401.7 (2A)
/labio-display/OLED_MOSI: P401.10, SW401.5 (4B)
/labio-display/OLED_SCK: P401.9, SW401.6 (3B)
/labio-display/VDD_3V3_F: F401.2, P401.2, P401.3, R403.2, R405.1
/labio-display/~OLED_CS: P401.6, R406.1, SW401.8 (1B)
/labio-display/~OLED_RES: C401.1, P401.7, R401.2, R404.2, R405.2
/labio-dpad/DPAD_UP: R401.1; also elsewhere on the board
/labio-rpi/GPIO8_SPI0_CE0_N: R404.1, SW401.1 (1A); also elsewhere on the board
/labio-rpi/GPIO10_SPI0_MOSI: SW401.4 (4A); also elsewhere on the board
/labio-rpi/GPIO11_SPI0_SCLK: SW401.3 (3A); also elsewhere on the board
GND: C401.2, P401.1, P401.12, R402.2, R406.2; also elsewhere on the board

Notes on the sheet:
CFAL12832D-B* OLED Display 3-wire SPI mode. Note: top side ZIF connector has pins reversed from FPC.
20mA approx max
FPC 1
FPC 12
Backup options for OLED reset line GPIO control on CS or alt or driven from VDD with an RC delay > 110ms.

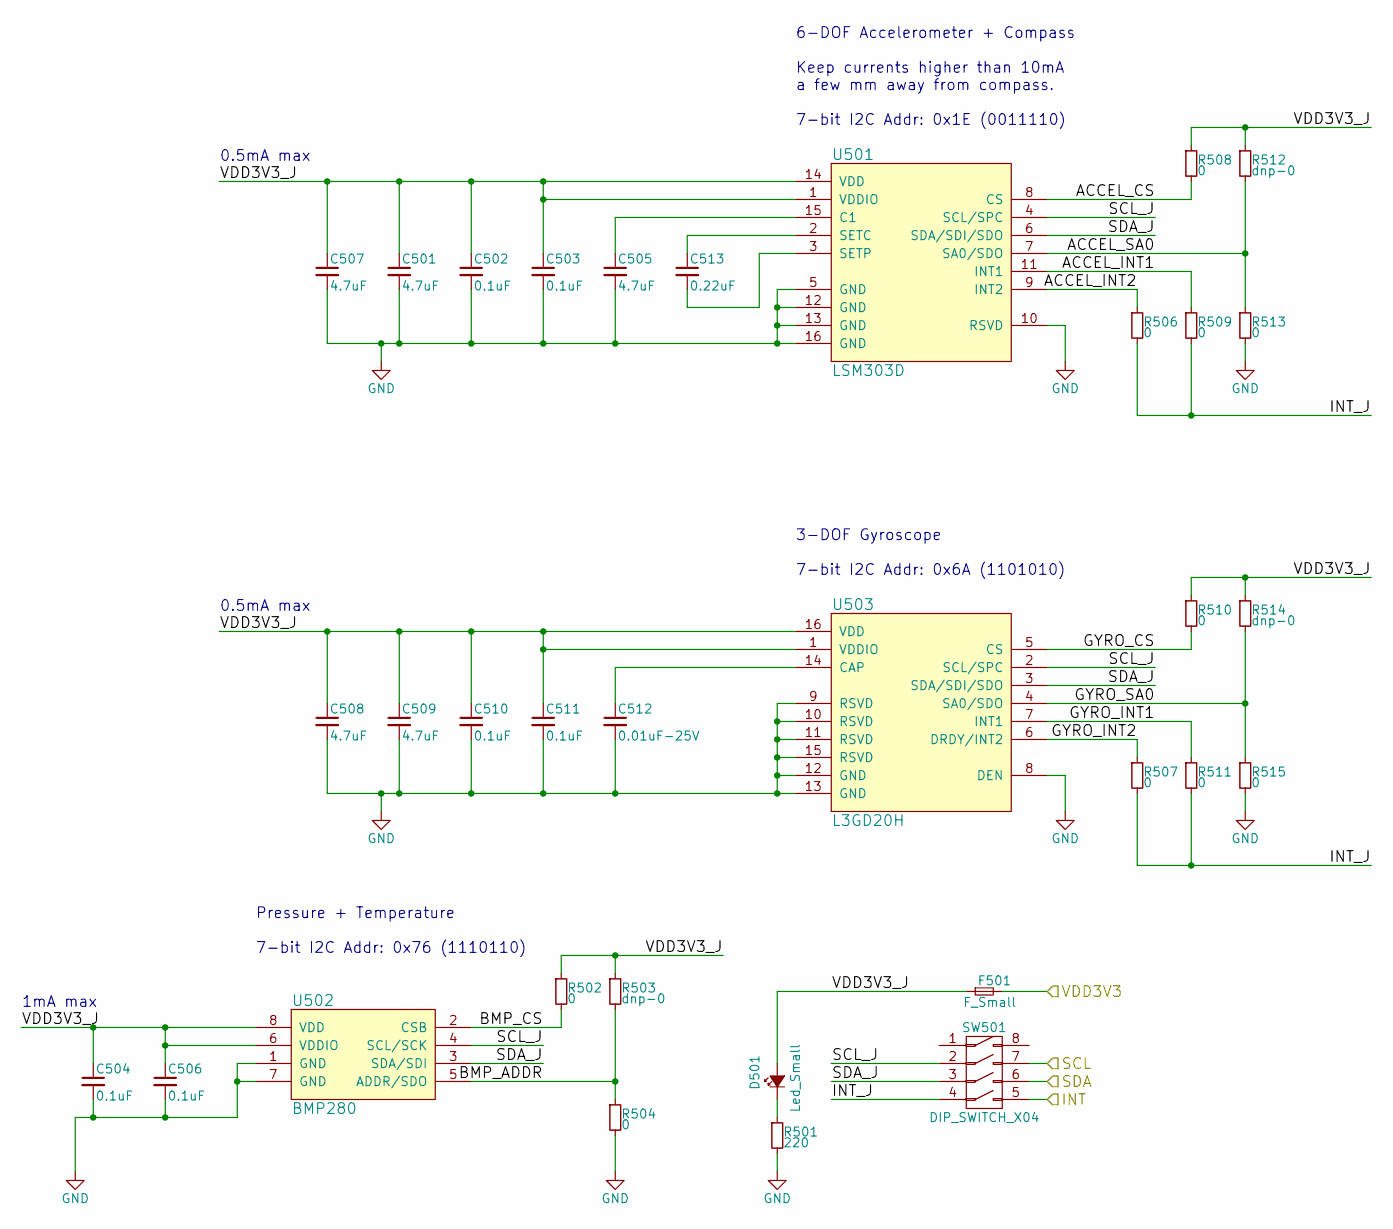
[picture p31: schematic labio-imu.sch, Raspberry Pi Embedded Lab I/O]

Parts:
C501, C505, C507, C508, C509: 4.7uF; C_0805
C502, C503, C504, C506, C510, C511: 0.1uF; C_0603
C512: 0.01uF-25V; C_0603
C513: 0.22uF; C_0603
D501: Led_Small; LED-0603
F501: F_Small; R_1206
R501: 220; R_0603
R502, R504, R506, R507, R508, R509, R510, R511, R513, R515: 0; R_0603
R503, R512, R514: dnp-0; R_0603
SW501: DIP_SWITCH_X04; DIP-8_W7.62mm_SMT
U501: LSM303D; LGA-16_3x3mm_Pitch0.5mm_ST
U502: BMP280; LGA-8_2.5x2.0mm_Pitch0.65mm_BMx280
U503: L3GD20H; LGA-16_3x3mm_Pitch0.5mm_ST

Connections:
/3V3_EXTRA: F501.2; also elsewhere on the board
/I2C_INT: SW501.5 (4B); also elsewhere on the board
/I2C_SCL: SW501.7 (2A); also elsewhere on the board
/I2C_SDA: SW501.6 (3B); also elsewhere on the board
/labio-imu/ACCEL_CS: R508.2, U501.8 (CS)
/labio-imu/ACCEL_INT1: R509.1, U501.11 (INT1)
/labio-imu/ACCEL_INT2: R506.1, U501.9 (INT2)
/labio-imu/ACCEL_SA0: R512.2, R513.1, U501.7 (SA0/SDO)
/labio-imu/BMP_ADDR: R503.2, R504.1, U502.5 (ADDR/SDO)
/labio-imu/BMP_CS: R502.2, U502.2 (CSB)
/labio-imu/GYRO_CS: R510.2, U503.5 (CS)
/labio-imu/GYRO_INT1: R511.1, U503.7 (INT1)
/labio-imu/GYRO_INT2: R507.1, U503.6 (DRDY/INT2)
/labio-imu/GYRO_SA0: R514.2, R515.1, U503.4 (SA0/SDO)
/labio-imu/INT_J: R506.2, R507.2, R509.2, R511.2, SW501.4 (4A)
/labio-imu/SCL_J: SW501.2 (2A), U501.4 (SCL/SPC), U502.4 (SCL/SCK), U503.2 (SCL/SPC)
/labio-imu/SDA_J: SW501.3 (3A), U501.6 (SDA/SDI/SDO), U502.3 (SDA/SDI), U503.3 (SDA/SDI/SDO)
/labio-imu/VDD3V3_J: C501.1, C502.1, C503.1, C504.1, C506.1, C507.1, C508.1, C509.1, C510.1, C511.1, D501.2 (A), F501.1, R502.1, R503.1, R508.1, R510.1, R512.1, R514.1, U501.1 (VDDIO), U501.14 (VDD), U502.6 (VDDIO), U502.8 (VDD), U503.1 (VDDIO), U503.16 (VDD)
GND: C501.2, C502.2, C503.2, C504.2, C505.2, C506.2, C507.2, C508.2, C509.2, C510.2, C511.2, C512.2, R501.2, R504.2, R513.2, R515.2, U501.5 (GND), U501.10 (RSVD), U501.12 (GND), U501.13 (GND), U501.16 (GND), U502.1 (GND), U502.7 (GND), U503.8 (DEN), U503.9 (RSVD), U503.10 (RSVD), U503.11 (RSVD), U503.12 (GND), U503.13 (GND), U503.15 (RSVD); also elsewhere on the board
unnamed: C505.1, U501.15 (C1)
unnamed: C512.1, U503.14 (CAP)
unnamed: C513.1, U501.2 (SETC)
unnamed: C513.2, U501.3 (SETP)
unnamed: D501.1 (K), R501.1

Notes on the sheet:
6-DOF Accelerometer + Compass Keep currents higher than 10mA a few mm away from compass. 7-bit I2C Addr: 0x1E (0011110)
Pressure + Temperature 7-bit I2C Addr: 0x76 (1110110)
0.5mA max
1mA max
3-DOF Gyroscope 7-bit I2C Addr: 0x6A (1101010)

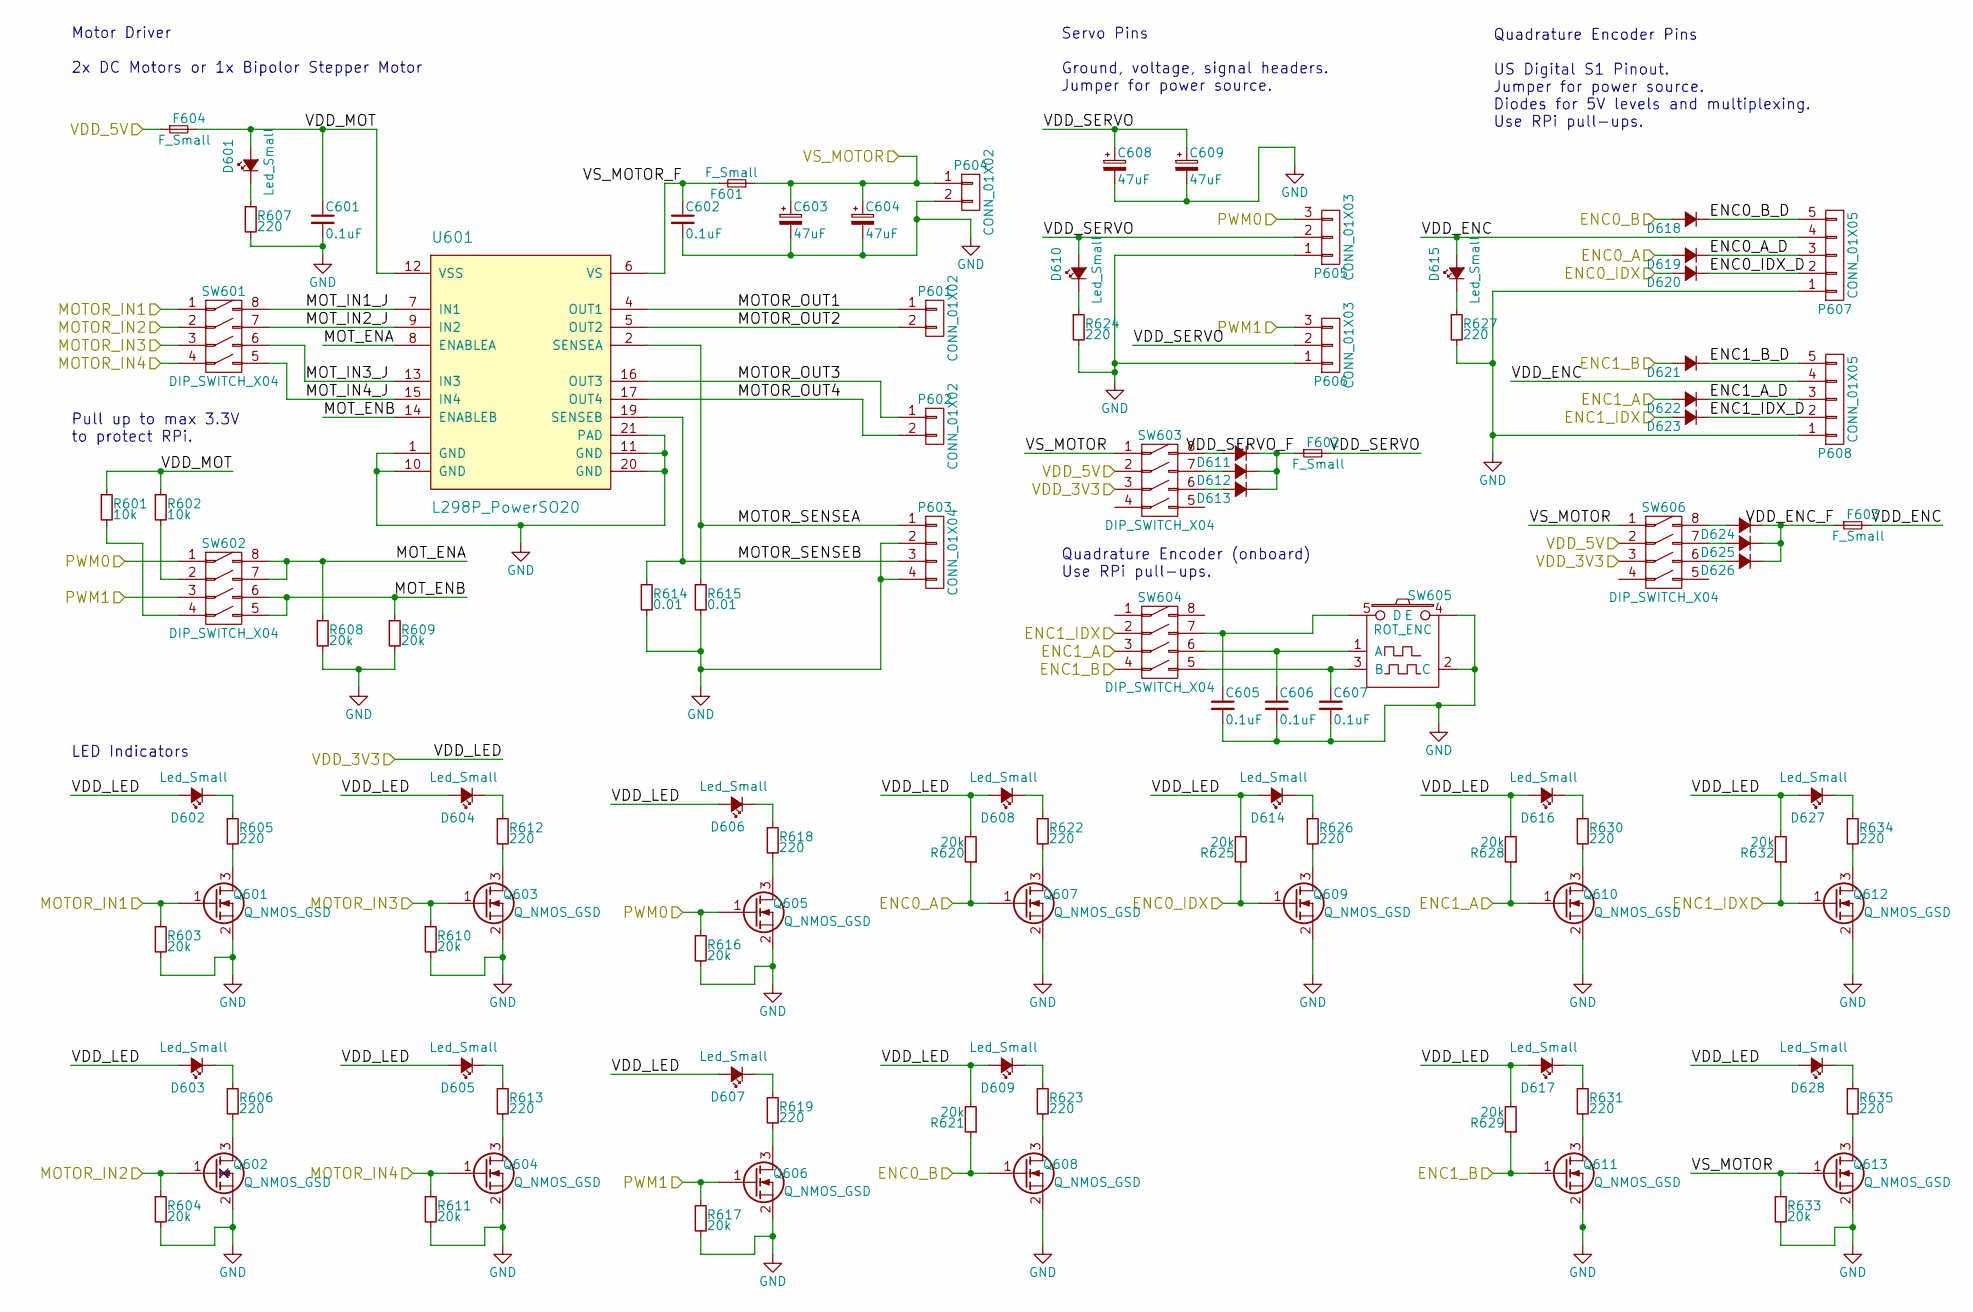
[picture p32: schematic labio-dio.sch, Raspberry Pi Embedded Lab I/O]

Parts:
C601, C602, C605, C606, C607: 0.1uF; C_0603
C603, C604, C608, C609: 47uF; c_elec_6.3x5.8
D601, D602, D603, D604, D605, D606, D607, D608, D609, D610, D614, D615, D616, D617, D627, D628: Led_Small; LED-0603
D611, D612, D613, D618, D619, D620, D621, D622, D623, D624, D625, D626: D_Small; SOD-523
F601: F_Small; OMNI-BLOCK_Fuse_10x5mm_Littelfuse
F602, F603, F604: F_Small; R_1206
P601, P602, P604: CONN_01X02; Pin_Header_Straight_1x02_Pitch3.5mm
P603: CONN_01X04; Pin_Header_Straight_1x04
P605, P606: CONN_01X03; Pin_Header_Straight_1x03
P607, P608: CONN_01X05; Pin_Header_Straight_1x05
Q601, Q602, Q603, Q604, Q605, Q606, Q607, Q608, Q609, Q610, Q611, Q612, Q613: Q_NMOS_GSD; SOT-23
R601, R602: 10k; R_0603
R603, R604, R608, R609, R610, R611, R616, R617, R620, R621, R625, R628, R629, R632, R633: 20k; R_0603
R605, R606, R607, R612, R613, R618, R619, R622, R623, R624, R626, R627, R630, R631, R634, R635: 220; R_0603
R614, R615: 0.01; R_1206
SW601, SW602, SW603, SW604, SW606: DIP_SWITCH_X04; DIP-8_W7.62mm_SMT
SW605: ROT_ENC; Rot-Enc-12mm-Horiz-Button
U601: L298P_PowerSO20; PowerSO20

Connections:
/3V3_EXTRA: D602.2 (A), D603.2 (A), D604.2 (A), D605.2 (A), D606.2 (A), D607.2 (A), D608.2 (A), D609.2 (A), D614.2 (A), D616.2 (A), D617.2 (A), D627.2 (A), D628.2 (A), R620.2, R621.2, R625.2, R628.2, R629.2, R632.2, SW603.3 (3A), SW606.3 (3A); also elsewhere on the board
/5V: F604.1, SW603.2 (2A), SW606.2 (2A); also elsewhere on the board
/I2C_INT: D619.2 (A), Q607.1 (G), R620.1; also elsewhere on the board
/I2S_BCLK: Q604.1 (G), R611.1, SW601.4 (4A); also elsewhere on the board
/I2S_LRCLK: Q603.1 (G), R610.1, SW601.3 (3A); also elsewhere on the board
/I2S_SDIN: Q601.1 (G), R603.1, SW601.1 (1A); also elsewhere on the board
/I2S_SDOUT: Q602.1 (G), R604.1, SW601.2 (2A); also elsewhere on the board
/PWM0: P605.3, Q605.1 (G), R616.1, SW602.1 (1A); also elsewhere on the board
/PWM1: P606.3, Q606.1 (G), R617.1, SW602.3 (3A); also elsewhere on the board
/labio-dio/ENC0_A_D: D619.1 (K), P607.3
/labio-dio/ENC0_B_D: D618.1 (K), P607.5
/labio-dio/ENC0_IDX_D: D620.1 (K), P607.2
/labio-dio/ENC1_A_D: D622.1 (K), P608.3
/labio-dio/ENC1_B_D: D621.1 (K), P608.5
/labio-dio/ENC1_IDX_D: D623.1 (K), P608.2
/labio-dio/MOTOR_OUT1: P601.1, U601.4 (OUT1)
/labio-dio/MOTOR_OUT2: P601.2, U601.5 (OUT2)
/labio-dio/MOTOR_OUT3: P602.1, U601.16 (OUT3)
/labio-dio/MOTOR_OUT4: P602.2, U601.17 (OUT4)
/labio-dio/MOTOR_SENSEA: P603.1, R615.1, U601.2 (SENSEA)
/labio-dio/MOTOR_SENSEB: P603.3, R614.1, U601.19 (SENSEB)
/labio-dio/MOT_ENA: R608.1, SW602.7 (2A), SW602.8 (1B), U601.8 (ENABLEA)
/labio-dio/MOT_ENB: R609.1, SW602.5 (4B), SW602.6 (3B), U601.14 (ENABLEB)
/labio-dio/MOT_IN1_J: SW601.8 (1B), U601.7 (IN1)
/labio-dio/MOT_IN2_J: SW601.7 (2A), U601.9 (IN2)
/labio-dio/MOT_IN3_J: SW601.6 (3B), U601.13 (IN3)
/labio-dio/MOT_IN4_J: SW601.5 (4B), U601.15 (IN4)
/labio-dio/VDD_ENC: D615.2 (A), F603.2, P607.4, P608.4
/labio-dio/VDD_ENC_F: D624.1 (K), D625.1 (K), D626.1 (K), F603.1
/labio-dio/VDD_MOT: C601.1, D601.2 (A), F604.2, R601.1, R602.1, U601.12 (VSS)
/labio-dio/VDD_SERVO: C608.1, C609.1, D610.2 (A), F602.2, P605.2, P606.2
/labio-dio/VDD_SERVO_F: D611.1 (K), D612.1 (K), D613.1 (K), F602.1
/labio-dio/VS_MOTOR: C603.1, C604.1, F601.1, P604.1, Q613.1 (G), R633.1, SW603.1 (1A), SW606.1 (1A); also elsewhere on the board
/labio-dio/VS_MOTOR_F: C602.1, F601.2, U601.6 (VS)
/labio-dpad/DPAD_CENTER: D622.2 (A), Q610.1 (G), R628.1, SW604.3 (3A); also elsewhere on the board
/labio-dpad/DPAD_DOWN: D623.2 (A), Q612.1 (G), R632.1, SW604.2 (2A); also elsewhere on the board
/labio-dpad/DPAD_LEFT: D618.2 (A), Q608.1 (G), R621.1; also elsewhere on the board
/labio-dpad/DPAD_RIGHT: D621.2 (A), Q611.1 (G), R629.1, SW604.4 (4A); also elsewhere on the board
/labio-dpad/DPAD_UP: D620.2 (A), Q609.1 (G), R625.1; also elsewhere on the board
GND: C601.2, C602.2, C603.2, C604.2, C605.2, C606.2, C607.2, C608.2, C609.2, P603.2, P603.4, P604.2, P605.1, P606.1, P607.1, P608.1, Q601.2 (S), Q602.2 (S), Q603.2 (S), Q604.2 (S), Q605.2 (S), Q606.2 (S), Q607.2 (S), Q608.2 (S), Q609.2 (S), Q610.2 (S), Q611.2 (S), Q612.2 (S), Q613.2 (S), R603.2, R604.2, R607.2, R608.2, R609.2, R610.2, R611.2, R614.2, R615.2, R616.2, R617.2, R624.2, R627.2, R633.2, SW605.2 (C), SW605.4 (E), U601.1 (GND), U601.10 (GND), U601.11 (GND), U601.20 (GND), U601.21 (PAD); also elsewhere on the board
unnamed: C605.1, SW604.7 (2A), SW605.5 (D)
unnamed: C606.1, SW604.6 (3B), SW605.1 (A)
unnamed: C607.1, SW604.5 (4B), SW605.3 (B)
unnamed: D601.1 (K), R607.1
unnamed: D602.1 (K), R605.1
unnamed: D603.1 (K), R606.1
unnamed: D604.1 (K), R612.1
unnamed: D605.1 (K), R613.1
unnamed: D606.1 (K), R618.1
unnamed: D607.1 (K), R619.1
unnamed: D608.1 (K), R622.1
unnamed: D609.1 (K), R623.1
unnamed: D610.1 (K), R624.1
unnamed: D611.2 (A), SW603.8 (1B)
unnamed: D612.2 (A), SW603.7 (2A)
unnamed: D613.2 (A), SW603.6 (3B)
unnamed: D614.1 (K), R626.1
unnamed: D615.1 (K), R627.1
unnamed: D616.1 (K), R630.1
unnamed: D617.1 (K), R631.1
unnamed: D624.2 (A), SW606.8 (1B)
unnamed: D625.2 (A), SW606.7 (2A)
unnamed: D626.2 (A), SW606.6 (3B)
unnamed: D627.1 (K), R634.1
unnamed: D628.1 (K), R635.1
unnamed: Q601.3 (D), R605.2
unnamed: Q602.3 (D), R606.2
unnamed: Q603.3 (D), R612.2
unnamed: Q604.3 (D), R613.2
unnamed: Q605.3 (D), R618.2
unnamed: Q606.3 (D), R619.2
unnamed: Q607.3 (D), R622.2
unnamed: Q608.3 (D), R623.2
unnamed: Q609.3 (D), R626.2
unnamed: Q610.3 (D), R630.2
unnamed: Q611.3 (D), R631.2
unnamed: Q612.3 (D), R634.2
unnamed: Q613.3 (D), R635.2
unnamed: R601.2, SW602.4 (4A)
unnamed: R602.2, SW602.2 (2A)

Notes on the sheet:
Quadrature Encoder Pins US Digital S1 Pinout. Jumper for power source. Diodes for 5V levels and multiplexing. Use RPi pull-ups.
Servo Pins Ground, voltage, signal headers. Jumper for power source.
Motor Driver 2x DC Motors or 1x Bipolor Stepper Motor
LED Indicators
Quadrature Encoder (onboard) Use RPi pull-ups.
Pull up to max 3.3V to protect RPi.

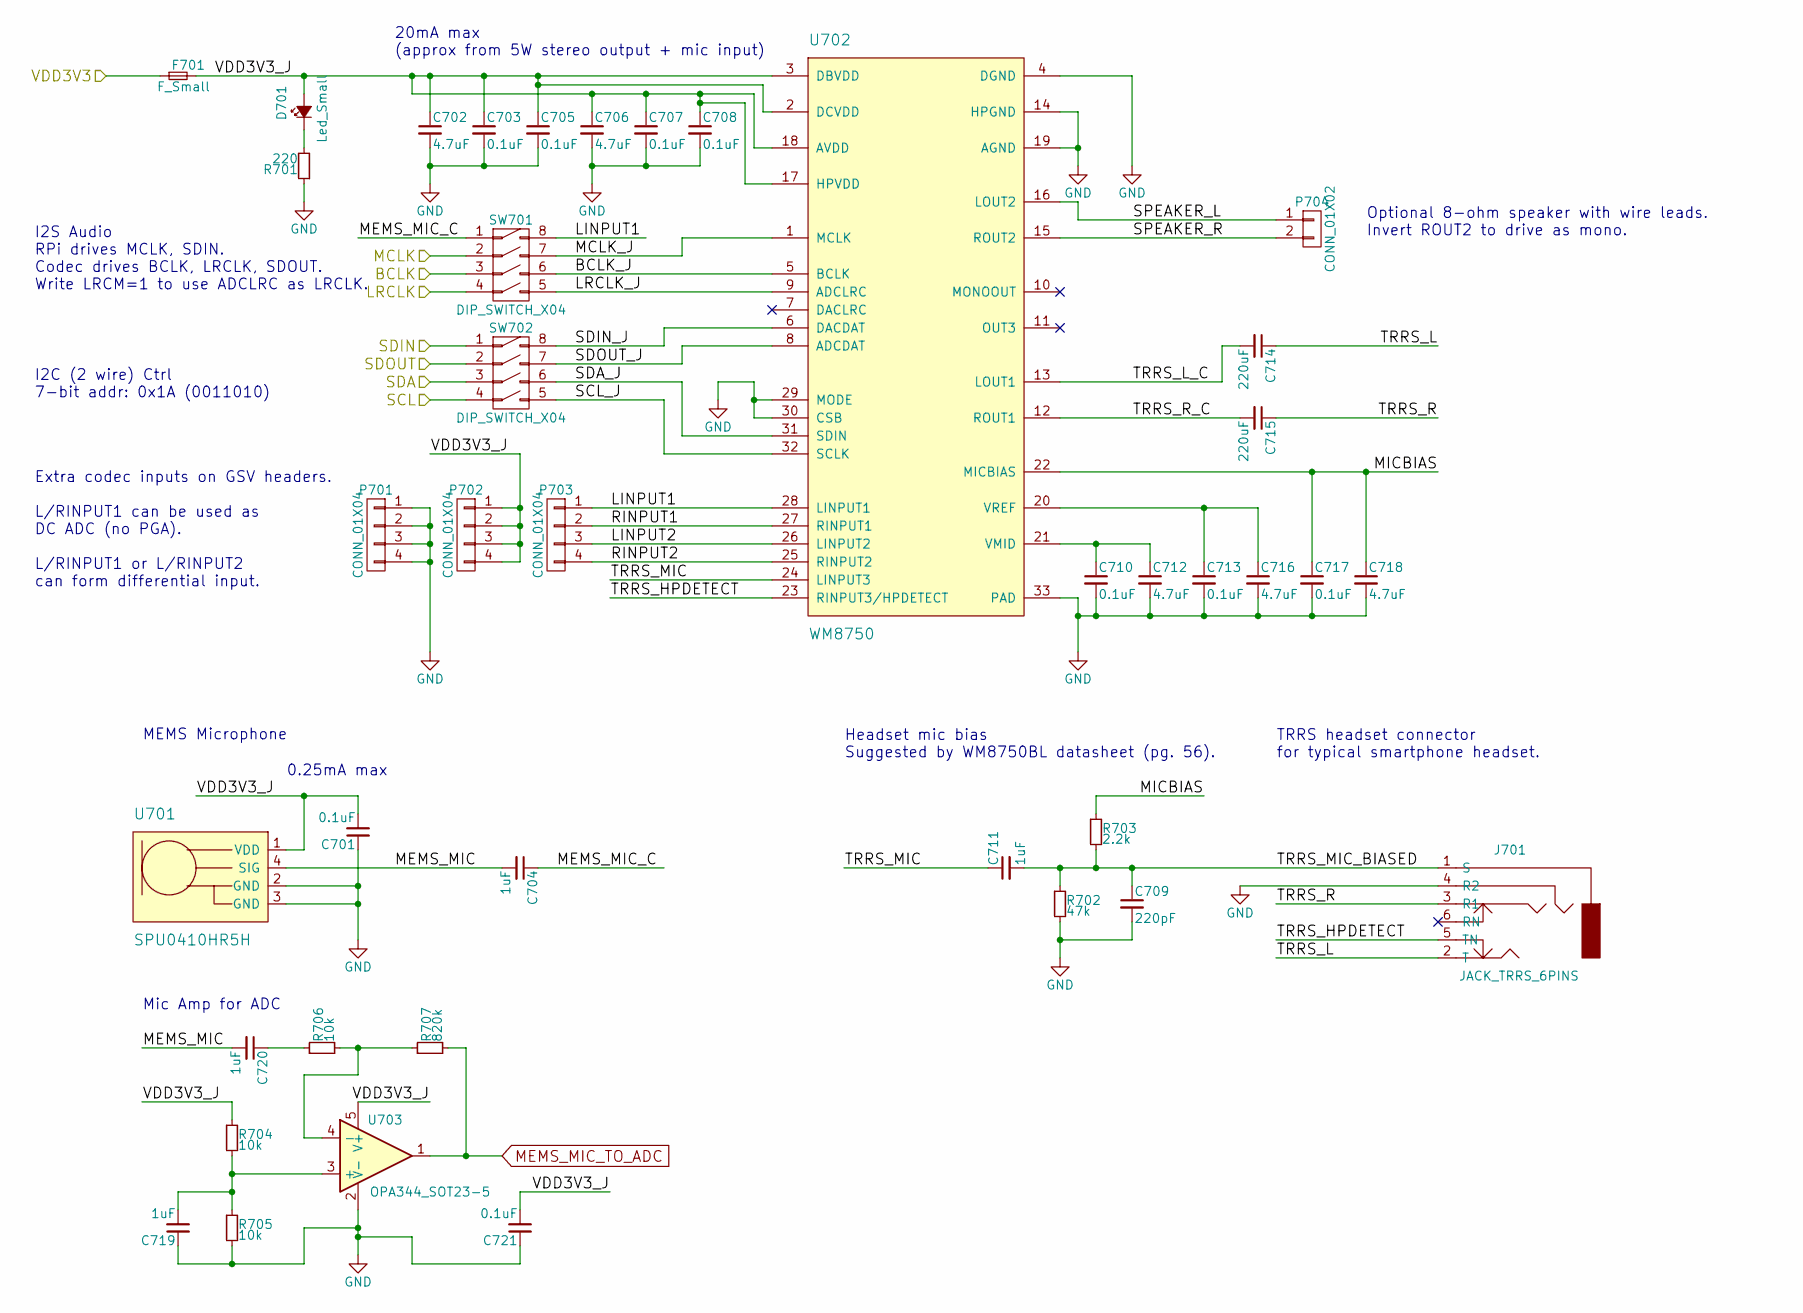
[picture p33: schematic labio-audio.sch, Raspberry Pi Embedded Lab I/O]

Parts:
C701, C703, C705, C707, C708, C710, C713, C717, C721: 0.1uF; C_0603
C702, C706, C712, C716, C718: 4.7uF; C_0805
C704, C711, C719, C720: 1uF; C_0603
C709: 220pF; C_0603
C714, C715: 220uF; C_1210
D701: Led_Small; LED-0603
F701: F_Small; R_1206
J701: JACK_TRRS_6PINS; 3.5mm-Jack-CUI-SJ-4351X
P701, P702, P703: CONN_01X04; Pin_Header_Straight_1x04
P704: CONN_01X02; Pin_Header_Straight_1x02
R701: 220; R_0603
R702: 47k; R_0603
R703: 2.2k; R_0603
R704, R705, R706: 10k; R_0603
R707: 820k; R_0603
SW701, SW702: DIP_SWITCH_X04; DIP-8_W7.62mm_SMT
U701: SPU0410HR5H
U702: WM8750; QFN-32-1EP_5x5mm_Pitch0.5mm
U703: OPA344_SOT23-5; SOT-23-5

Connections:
/3V3_EXTRA: F701.1; also elsewhere on the board
/GPCLK1: SW701.2 (2A); also elsewhere on the board
/I2C_SCL: SW702.4 (4A); also elsewhere on the board
/I2C_SDA: SW702.3 (3A); also elsewhere on the board
/I2S_BCLK: SW701.3 (3A); also elsewhere on the board
/I2S_LRCLK: SW701.4 (4A); also elsewhere on the board
/I2S_SDIN: SW702.1 (1A); also elsewhere on the board
/I2S_SDOUT: SW702.2 (2A); also elsewhere on the board
/labio-audio/BCLK_J: SW701.6 (3B), U702.5 (BCLK)
/labio-audio/LINPUT1: P703.1, SW701.8 (1B), U702.28 (LINPUT1)
/labio-audio/LINPUT2: P703.3, U702.26 (LINPUT2)
/labio-audio/LRCLK_J: SW701.5 (4B), U702.9 (ADCLRC)
/labio-audio/MCLK_J: SW701.7 (2A), U702.1 (MCLK)
/labio-audio/MEMS_MIC: C704.2, C720.2, U701.4 (SIG)
/labio-audio/MEMS_MIC_C: C704.1, SW701.1 (1A)
/labio-audio/MICBIAS: C717.1, C718.1, R703.1, U702.22 (MICBIAS)
/labio-audio/RINPUT1: P703.2, U702.27 (RINPUT1)
/labio-audio/RINPUT2: P703.4, U702.25 (RINPUT2)
/labio-audio/SCL_J: SW702.5 (4B), U702.32 (SCLK)
/labio-audio/SDA_J: SW702.6 (3B), U702.31 (SDIN)
/labio-audio/SDIN_J: SW702.8 (1B), U702.6 (DACDAT)
/labio-audio/SDOUT_J: SW702.7 (2A), U702.8 (ADCDAT)
/labio-audio/SPEAKER_L: P704.1, U702.16 (LOUT2)
/labio-audio/SPEAKER_R: P704.2, U702.15 (ROUT2)
/labio-audio/TRRS_HPDETECT: J701.5 (TN), U702.23 (RINPUT3/HPDETECT)
/labio-audio/TRRS_L: C714.1, J701.2 (T)
/labio-audio/TRRS_L_C: C714.2, U702.13 (LOUT1)
/labio-audio/TRRS_MIC: C711.1, U702.24 (LINPUT3)
/labio-audio/TRRS_MIC_BIASED: C709.1, C711.2, J701.1 (S), R702.1, R703.2
/labio-audio/TRRS_R: C715.1, J701.3 (R1)
/labio-audio/TRRS_R_C: C715.2, U702.12 (ROUT1)
/labio-audio/VDD3V3_J: C701.2, C702.1, C703.1, C705.1, C706.1, C707.1, C708.1, C721.2, D701.2 (A), F701.2, P702.1, P702.2, P702.3, P702.4, R704.1, U701.1 (VDD), U702.2 (DCVDD), U702.3 (DBVDD), U702.17 (HPVDD), U702.18 (AVDD), U703.5 (V+)
GND: C701.1, C702.2, C703.2, C705.2, C706.2, C707.2, C708.2, C709.2, C710.2, C712.2, C713.2, C716.2, C717.2, C718.2, C719.1, C721.1, J701.4 (R2), P701.1, P701.2, P701.3, P701.4, R701.1, R702.2, R705.2, U701.2 (GND), U701.3 (GND), U702.4 (DGND), U702.14 (HPGND), U702.19 (AGND), U702.29 (MODE), U702.30 (CSB), U702.33 (PAD), U703.2 (V-); also elsewhere on the board
MEMS_MIC_TO_ADC: R707.2, U703.1; also elsewhere on the board
unnamed: C710.1, C712.1, U702.21 (VMID)
unnamed: C713.1, C716.1, U702.20 (VREF)
unnamed: C719.2, R704.2, R705.1, U703.3 (+)
unnamed: C720.1, R706.1
unnamed: D701.1 (K), R701.2
unnamed: R706.2, R707.1, U703.4 (-)

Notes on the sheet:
Optional 8-ohm speaker with wire leads. Invert ROUT2 to drive as mono.
MEMS Microphone
Extra codec inputs on GSV headers. L/RINPUT1 can be used as DC ADC (no PGA). L/RINPUT1 or L/RINPUT2 can form differential input.
TRRS headset connector for typical smartphone headset.
I2S Audio RPi drives MCLK, SDIN. Codec drives BCLK, LRCLK, SDOUT. Write LRCM=1 to use ADCLRC as LRCLK.
I2C (2 wire) Ctrl 7-bit addr: 0x1A (0011010)
Headset mic bias Suggested by WM8750BL datasheet (pg. 56).
0.25mA max
20mA max (approx from 5W stereo output + mic input)
Mic Amp for ADC

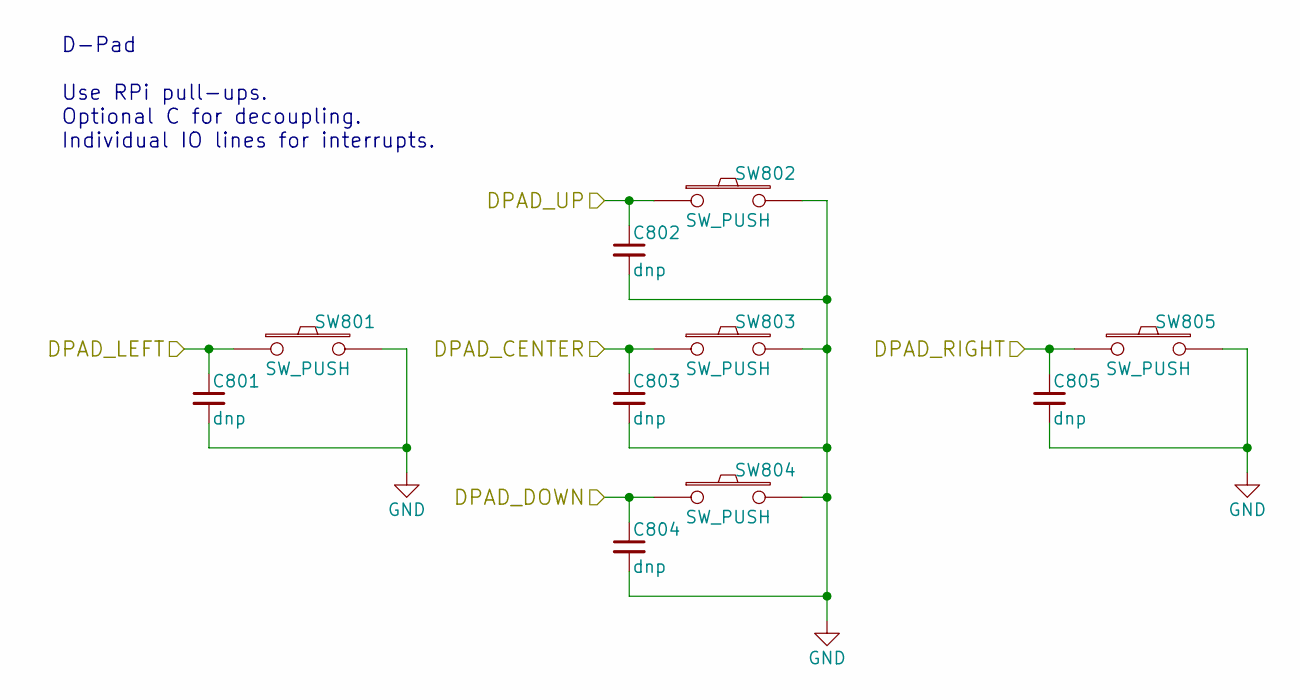
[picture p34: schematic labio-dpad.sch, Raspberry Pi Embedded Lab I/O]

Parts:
C801, C802, C803, C804, C805: dnp; C_0603
SW801, SW802, SW803, SW804, SW805: SW_PUSH; SW_SPST_EVPBF

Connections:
/labio-dpad/DPAD_CENTER: C803.1, SW803.1; also elsewhere on the board
/labio-dpad/DPAD_DOWN: C804.1, SW804.1; also elsewhere on the board
/labio-dpad/DPAD_LEFT: C801.1, SW801.1; also elsewhere on the board
/labio-dpad/DPAD_RIGHT: C805.1, SW805.1; also elsewhere on the board
/labio-dpad/DPAD_UP: C802.1, SW802.1; also elsewhere on the board
GND: C801.2, C802.2, C803.2, C804.2, C805.2, SW801.2, SW802.2, SW803.2, SW804.2, SW805.2; also elsewhere on the board

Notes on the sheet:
D-Pad Use RPi pull-ups. Optional C for decoupling. Individual IO lines for interrupts.

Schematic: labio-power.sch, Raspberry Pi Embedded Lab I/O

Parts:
P901: CONN_01X06; Pin_Header_Angled_1x06

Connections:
/5V: P901.6; also elsewhere on the board
/labio-dio/VS_MOTOR: P901.1, P901.2; also elsewhere on the board
GND: P901.3, P901.4; also elsewhere on the board

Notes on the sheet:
External Power (Future) Provides logic and motor power from power supply or battery pack with possible charging from USB (rpi) power. 2x motor power for current rating.

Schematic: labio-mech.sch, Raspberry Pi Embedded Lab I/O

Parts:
G1: CMU_LOGO; cmu_logo_fsilk_3.7mm
G2: WISE_LOGO; wise_logo_fsilk_2.5mm
G3: CMU_LOGO; cmu_logo_fcu_3.7mm
G4: WISE_LOGO; wise_logo_fcu_2.5mm
H1001, H1002, H1003, H1004, H1005, H1006, H1007, H1008, H1009: hole; hole-m3

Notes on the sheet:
RPi-like Mounting Holes M3 for M3/no 4/M2.5 hardware.
Heatsink Mounting 25x25mm with 30x30mm M3 holes

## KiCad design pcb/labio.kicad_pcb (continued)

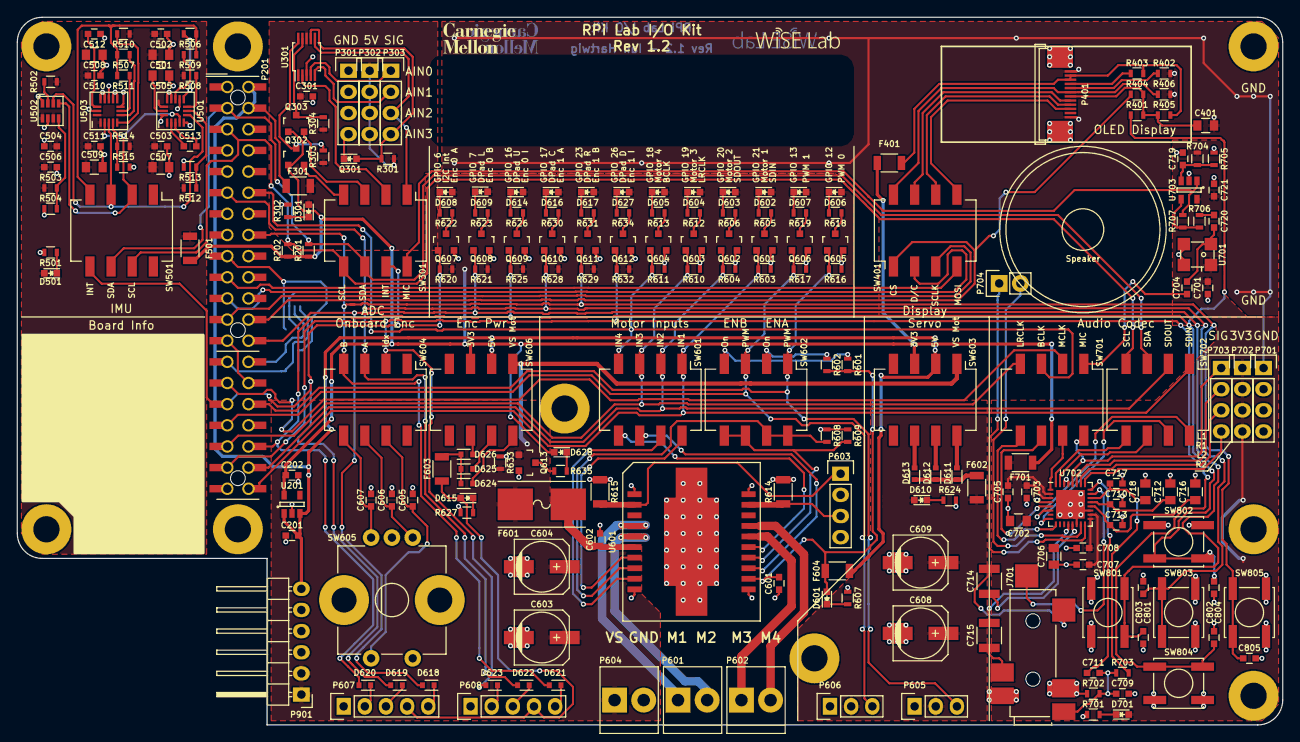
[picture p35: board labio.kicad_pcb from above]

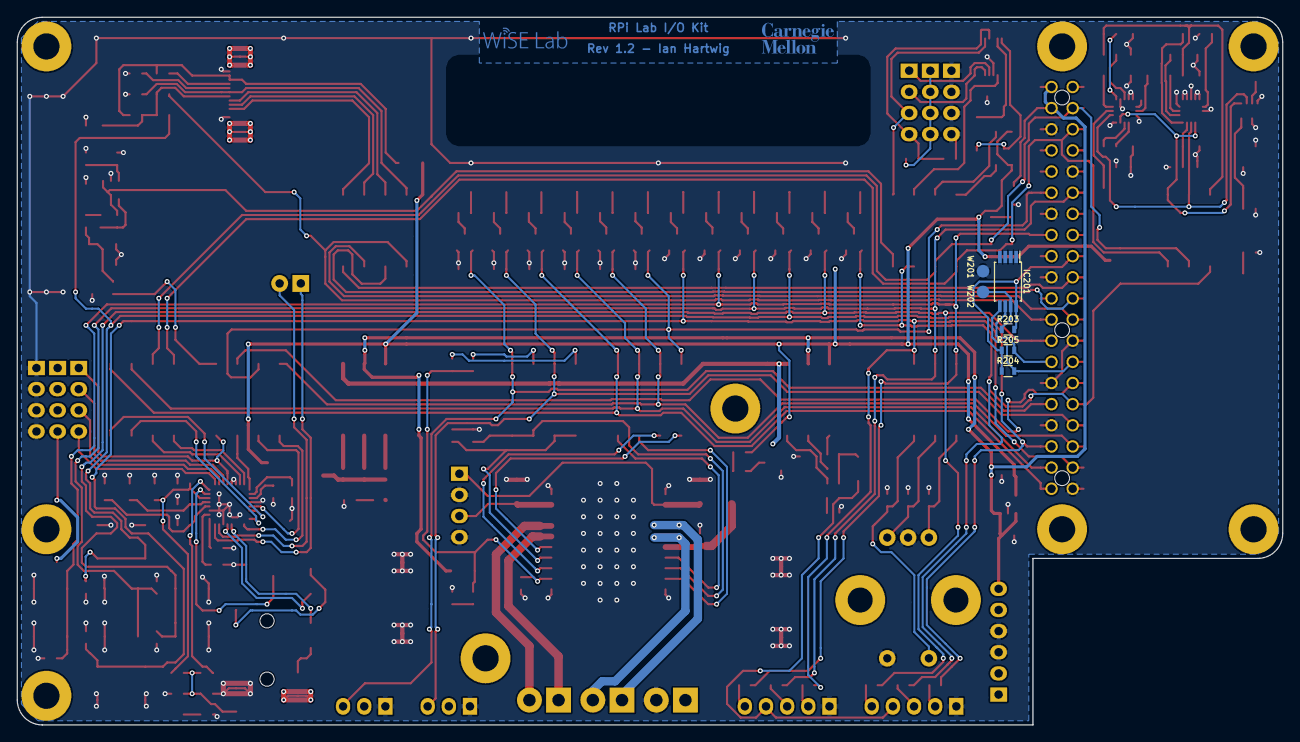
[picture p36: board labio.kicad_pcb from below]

Board: 2 copper layers, 152.0 x 85.0 mm, 238 parts (8 on the bottom side), 160 nets.

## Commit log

2016-06-11 schematic pages for rpi header, adc, audio
    [labio-accel.sch, labio-adc.sch, labio-audio.sch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]
2016-06-11 add schematics for display and dio (dpad, servo, motor, encoder)
    [labio-accel.sch, labio-adc.sch, labio-audio.sch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]
2016-06-19 add imu sensors, make top level connections
    [labio-accel.sch, labio-adc.sch, labio-audio.sch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]
2016-06-24 finish rpi to module connections
    * use dip switches to disable/configure blocks
    * add light sensor
    * fix motor controller sense resistors
    * fix overused jtag probe pins
    [labio-adc.sch, labio-audio.sch, labio-dio.sch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]
2016-06-25 add led status indicators, rotary encoder
    * add led indicators for motor direction, pwm, encoder (muxed with dpad) pins
    * add led indicators for power in all blocks
    * split dpad into a different page
    * add selectable onboard rotary encoder for testing or user input
    [labio-adc.sch, labio-audio.sch, labio-dio.sch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]
2016-07-03 make extra footprints. start floorplan. fix display nets. add power expansion header.
    [labio-adc.sch, labio-audio.sch, labio-dio.sch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]
2016-07-10 floorplan on 150x85mm board, use al caps for motors
    [labio-audio.sch, labio-dio.sch, labio-dpad.sch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]
2016-07-16 first pass routing, fixed audio header 3v3 net
    [labio-audio.sch, labio-dpad.sch, labio-imu.sch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]
2016-07-18 update imu parts, adc rails, motor headers
    * replace LSM303C accelerometer with LSM303D for better sensor ranges at same cost.
    * add L3GD20H gyroscope so we have a 10-DOF imu. consider leaving depopulated for complexity.
    * add 0 ohms to accel/gyro address and interrupt pins in case of later changes
    * change ADC rails to 5V to read 5V power shunts. add level shifters to the 3.3V I2C bus.
    * use 3.5mm pitch headers for motor terminal blocks to accept higher guage wire.
    todo:
    * redo ADC routing
    * make space behind motor headers
    [labio-adc.sch, labio-audio.sch, labio-dio.sch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]
2016-07-19 finish rerouting for new parts
    * fix adc power supply nets
    * redo adc layout
    * move motor controller up to make space for headers
    * add motor controller heatsink mount
    * fix motor controller ground pad net
    * silkscreen
    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
    [labio-adc.sch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]
2016-07-19 combine gnd and gnda nets per mixed signal layout suggestions from analog, ti
    [labio-audio.sch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]
2016-07-20 expand outline to 175x85mm. move screen zif connector to top
    [labio-audio.sch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]
2016-07-24 shrink board to 85x150mm with tab board under rpi 0/debugger
    * use space under rpi 0/debugger for imu since no visibility is needed
    * rearrange dpad buttons and speaker to be more compact
    * use 3V3_EXTRA for i2c pullups for consistency
    * add bottom right hole to match future power module
    [labio-B.Cu.gbl, labio-B.Mask.gbs, labio-B.Paste.gbp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]
2016-07-25 add cmu + wise logos, clean up silk, review for final errors
    * move audio jack in so copper pads are inside board
    * add logos/identifier text on silk and copper
    * change rpi connector for no paste (to be left depopulated at fab)
    * change soldermask expansion to 2 mils/3 mils minimum width
    * add labels for motor, ADC, codec headers
    [labio-B.Cu.gbl, labio-B.Mask.gbs, labio-B.Paste.gbp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]
2016-07-25 update readme, export only board in svg
    [labio.kicad_pcb]
2016-07-26 add bom. change led resistors to 220 and dnp rpi hat eeprom
    [labio-adc.sch, labio-audio.sch, labio-dio.sch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]
2016-08-01 Fix board/bom errors from initial build
    * Accelerometer (U501) footprint mirrored. Redraw footprint and adjust routing.
    * Gyro (U505) footprint mirrored. Redraw footprint and adjust routing.
    * Codec (U702) labed as wrong chip. Says WM8731 but should be 8750. Also fix in BOM.
    * Should include OLED screen in BOM (not just the connector).
    * Codec to TRRS caps have incorrect value. Says 220uF but should be 220pF.
    * Mark RPi Hat EEPROM circuit as depopulated in schematic.
    * Remove dangling trace near encoder headers.
    [labio-B.Cu.gbl, labio-B.Mask.gbs, labio-B.Paste.gbp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]
2016-08-01 Use soldermask windows on footprints with thermal pads (motor driver, codec)
    [labio-B.Cu.gbl, labio-B.Mask.gbs, labio-B.Paste.gbp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]
2016-08-02 improve codec and motor driver soldermask windows to avoid convex 90 deg angles
    [footprints.dwg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]
2016-08-05 Power motor driver from 5V but with 3.3V logic. Adjust R601, R602 to prevent more than 3.3V on logic lines.
    [labio-B.Cu.gbl, labio-B.Mask.gbs, labio-B.Paste.gbp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]
2016-08-06 add fuses for connectable headers (adc, encoder, motors, servo, codec). GERBER/BOM UPDATES ONLY
    [labio-B.Cu.gbl, labio-B.Mask.gbs, labio-B.Paste.gbp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]
2016-08-11 fix codec/mic/trrs bias circuit
    * trrs (headset) mic bias was flipped (in vs out) from datasheet
    * trrs l/r decoupling caps changed back to 220uF per datasheet and re-layout for 1210 ceramic
    * mems mic decoupling changed to 1uF for consistency
    [labio-B.Cu.gbl, labio-B.Mask.gbs, labio-B.Paste.gbp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]
2016-08-14 Fix ADC reading mic, possible backpowering, encoder pull downs, vias in footprint:
    * Mic needs on-board path to ADC. Add proper bias and amp. Connect to ADC or codec with switches.
    * Mic footprint (U701) flipped. Redraw footprint and adjust routing.
    * Remove power from dip switches and replace with fuses. Turning power off to a block could result in backpower from driven IO lines.
    * Remove/adjust pull downs on LEDs for encoder/dpad lines.
    * Move vias out of display connector (P401) footprint.
    [labio-B.Cu.gbl, labio-B.Mask.gbs, labio-B.Paste.gbp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]
2016-08-14 adjust vdd servo, vdd codec pours
    [labio-B.Cu.gbl, labio-B.Mask.gbs, labio-B.Paste.gbp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]
2016-08-15 Fix i2c addresses, pressure sensor footprint, consolidate BOM
    * Schematic should list I2C addresses for accelerometer, gyro.
    * Pressure sensor footprint (U502) has pins in the wrong order. Redraw footprint and adjust routing.
    * Bump i2c and photodiode pullups to 2.2k
    * Remove R505 near gyro
    [labio-B.Cu.gbl, labio-B.Mask.gbs, labio-B.Paste.gbp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]
2016-08-15 add pdf schematic for a154e58
2016-08-20 using MISO/gpio for D/C on led screen and layout. bump to rev 1.2.0.
    [labio-B.Cu.gbl, labio-B.Mask.gbs, labio-B.Paste.gbp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]
2016-08-22 fix parts missing from bom (using pos export) and fill in passive part nos
    [labio.bom.xlsx]
2016-08-24 add options for driving oled reset. no changes to stuffed bom parts.
    [labio-B.Cu.gbl, labio-B.Mask.gbs, labio-B.Paste.gbp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]
2016-08-24 add through hole parts to the bom (highlighted). update schematic pdf.
    [labio-display.sch, labio.bom.xlsx]
2016-10-26 fix bom qty for P601 P602 P604 (screw in header)
    [labio.bom.xlsx]
2017-08-02 add prelim cover design and explaination
    [labio-cover.dwg]
2017-08-04 complete cover designs b/c/d for prototyping
    [labio-cover-all.dxf, labio-cover.dwg]
2017-08-07 finish pi 2 top cover. arrange cover sets for cutting protos.
    [labio-cover-all.dxf, labio-cover-b-set.dxf, labio-cover.dwg]
2017-08-13 fix cover details after first proto. add set a cut files.
    * don't cover d-pad buttons
    * expand area around screen
    * expand area around pi 2/3 ribbon connectors
    * pi 2/3 cutouts for caps near ports
    * expand area around sd card
    * complete set a mounting holes
    * add cutout for debugger reset button
    [labio-cover-a-set-3x.dxf, labio-cover-all.dxf, labio-cover-b-set.dxf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]
2017-08-20 complete cover BOM, fixes, and cutting sets. refresh readmes
    add cutting sets for C and D covers
    fix pi 2/3 usb port on cover
    complete cover BOM with part links
    [labio-cover-a-set-3x.dxf, labio-cover-all.dxf, labio-cover-c-set.dxf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]
